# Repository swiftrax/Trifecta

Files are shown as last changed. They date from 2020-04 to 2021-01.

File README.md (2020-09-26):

# Trifecta

A 65% Alice with per key RGB, RGB backlighting and 3 rotary encoders. Designed by 2Moons-JP and swiftrax

# Render

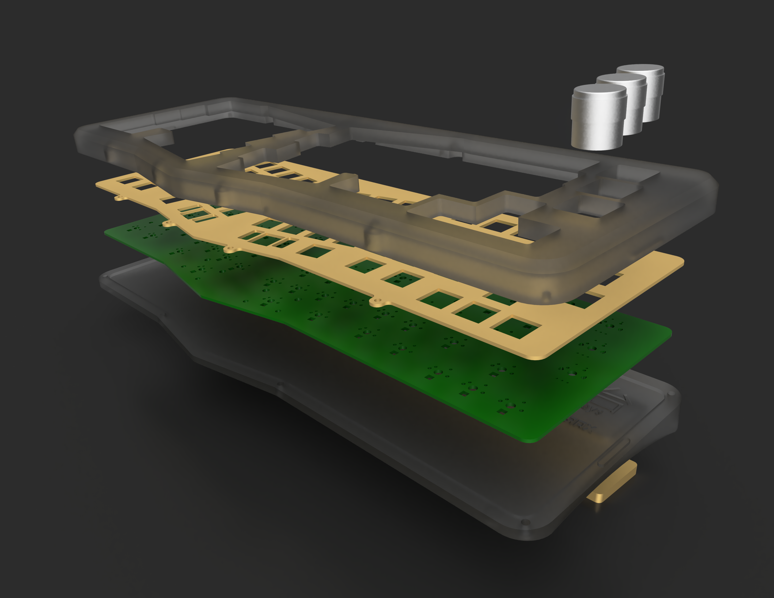
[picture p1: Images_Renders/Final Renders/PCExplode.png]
Renders


# Proto Image

Smoky PC

## License

This repository is under the [GNU GPL V2 license](https://github.com/swiftrax/Trifecta/blob/master/LICENSE). If you plan to sell these pcbs, make sure to read it.

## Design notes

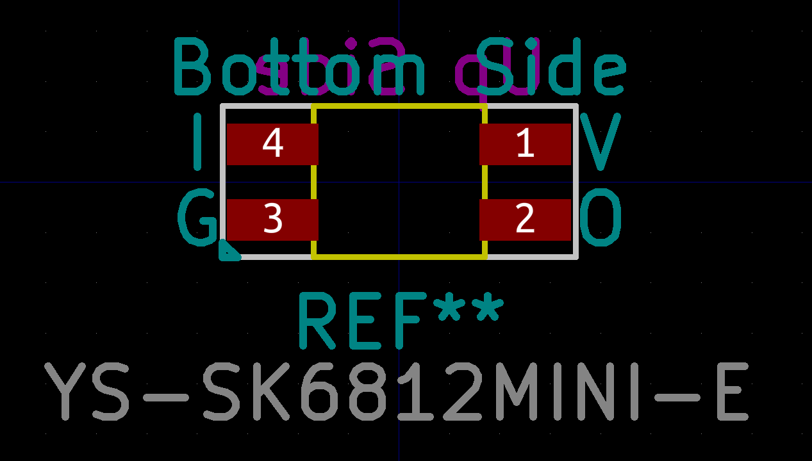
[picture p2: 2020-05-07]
Hardware/Rev06rgbstm32 12Deg/LED_kicad_footprints-master/YS-SK6812MINI-E.png

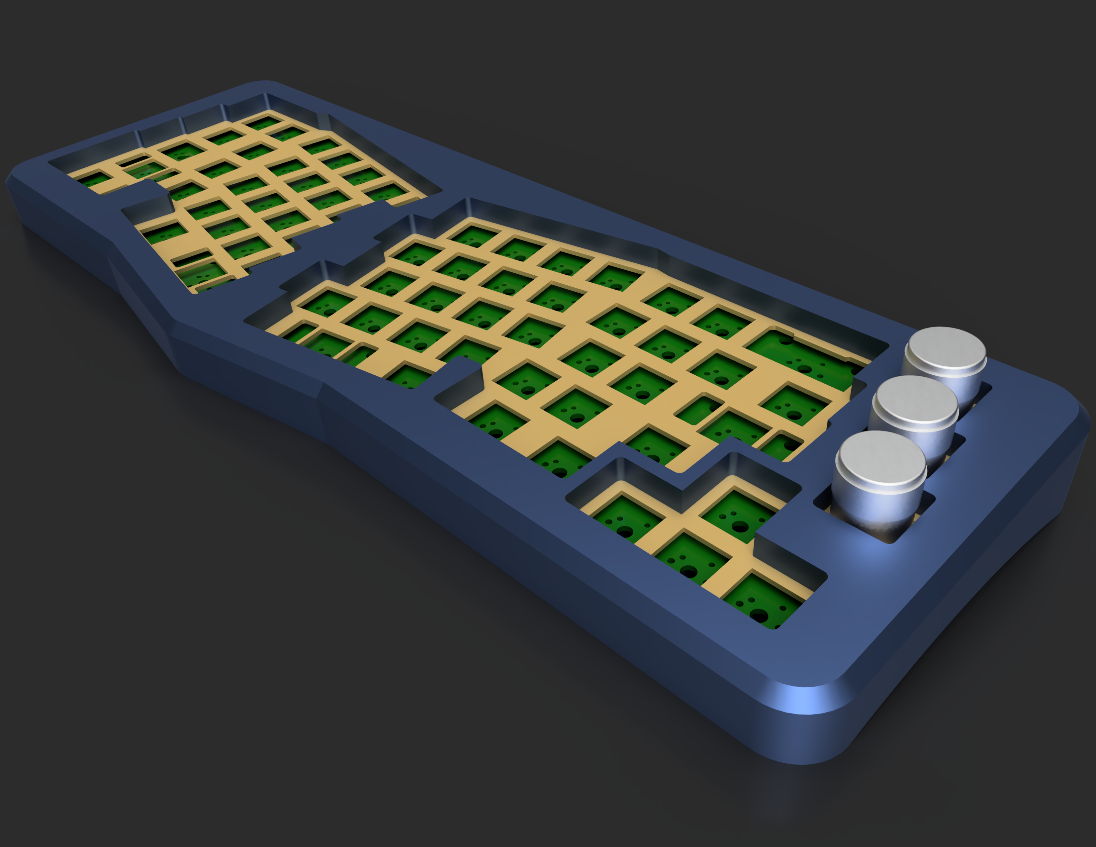
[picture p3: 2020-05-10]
Images_Renders/Final Renders/BlueISO.png

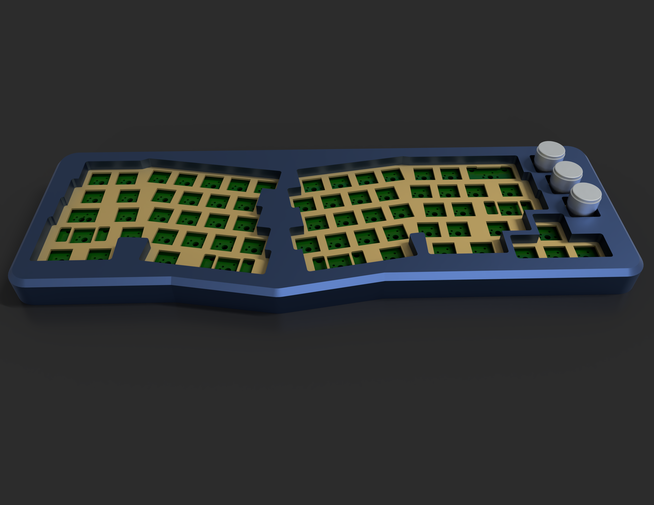
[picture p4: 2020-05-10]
Images_Renders/Final Renders/TypingAngle.png

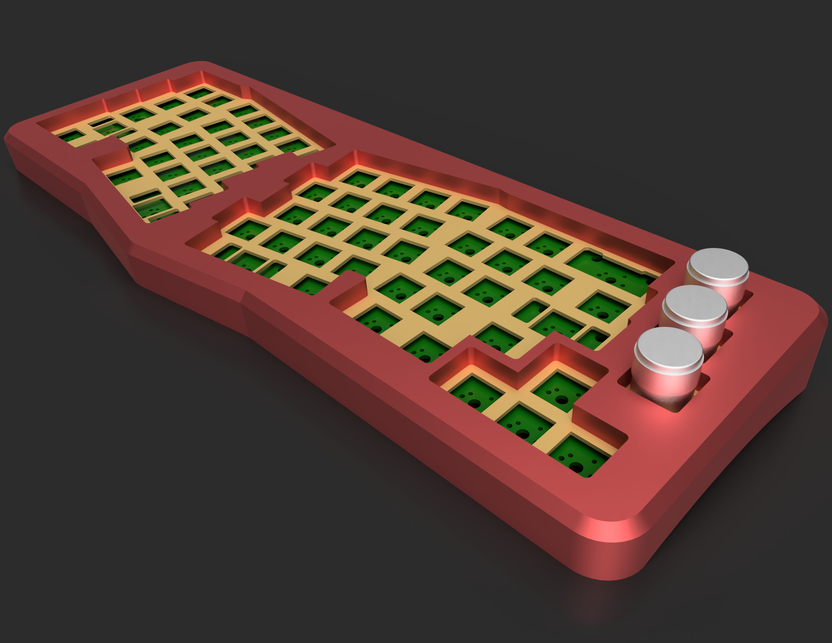
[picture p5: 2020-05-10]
Images_Renders/Final Renders/RedISO.png

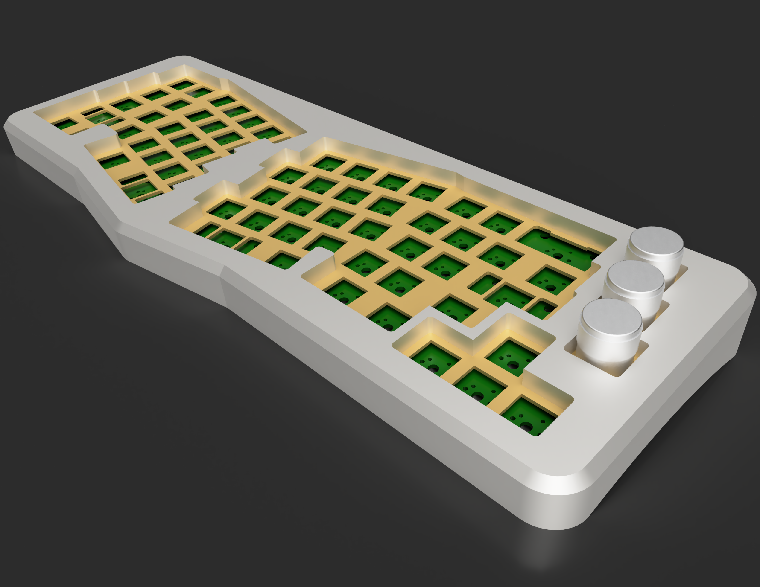
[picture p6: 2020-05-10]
Images_Renders/Final Renders/EWhiteISO.png

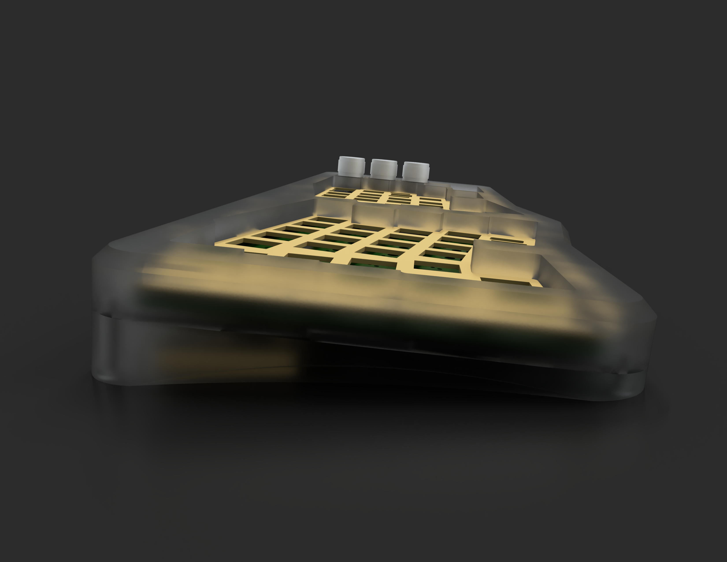
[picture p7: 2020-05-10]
Images_Renders/Final Renders/PCSide.png

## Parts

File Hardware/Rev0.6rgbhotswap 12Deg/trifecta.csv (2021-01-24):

Comment | Designator | Footprint | LCSC | LCSC Part# | Mrf | Part# | Mfr
1uF | C1 | Capacitor_SMD:C_0805_2012Metric |  | C28323 |  | CL21B105KBFNNNE | Samsung Electro-Mechanics
10uF | C16 | Capacitor_SMD:C_0805_2012Metric |  | C15850 |  | CL21A106KAYNNNE | Samsung Electro-Mechanics
0.1uF | C9,C11,C13,C2,C18,C34,C48,C63,C4,C20,C36,C50,C6,C22,C38,C52,C8,C24,C40,C54,C66,C10,C26,C42,C56,C67,C12,C28,C44,C58,C69,C15,C30,C45,C60,C71,C72,C73,C74,C75,C76,C77,C78,C79 | Capacitor_SMD:C_0805_2012Metric |  | C49678 | YAGEO | CC0805KRX7R9BB104
D | D_1,D_17,D_33,D_47,D_62,D_2,D_18,D_34,D_48,D_63,D_3,D_19,D_35,D_49,D_64,D_4,D_20,D_36,D_50,D_5,D_21,D_37,D_51,D_65,D_6,D_22,D_38,D_52,D_7,D_23,D_39,D_53,D_8,D_24,D_40,D_54,D_66,D_9,D_25,D_41,D_55,D_10,D_26,D_42,D_56,D_67,D_11,D_27,D_43,D_57,D_68,D_12,D_28,D_44,D_58,D_69,D_29,D_59,D_70,D_15,D_30,D_45,D_60,D_71,D_16,D_31,D_46,D_61,D_72,D_13 | kbd:D3_SMD_v2 |  | C81598 | Semtech | 1N4148W
500mA | F1 | Fuse:Fuse_1206_3216Metric |  | C70068 |  | nSMD025 | TECHFUSE
USB2_C_Receptacle | J1 | usb-type-c:Mid_Mount-USB_C_HandSoldering
ISP Header | J2 | Connector_PinHeader_2.54mm:PinHeader_2x03_P2.54mm_Vertical
KEYSW | K_1,K_2,K_18,K_34,K_48,K_3,K_19,K_35,K_49,K_4,K_20,K_36,K_50,K_5,K_21,K_37,K_51,K_6,K_22,K_38,K_52,K_7,K_23,K_39,K_53,K_8,K_24,K_40,K_54,K_9,K_25,K_41,K_55,K_10,K_26,K_42,K_56,K_11,K_27,K_43,K_57,K_12,K_28,K_44,K_58,K_13,K_29,K_70,K_14,K_30,K_60,K_71,K_16,K_31,K_46,K_61,K_72 | MX_Only:MXOnly-1U-NoLED
KEYSW | K_15 | MX_Only:MXOnly-2U-ReversedStabilizers-NoLED
KEYSW | K_17 | MX_Only:MXOnly-1.5U-NoLED
KEYSW | K_32,K_33,K_59 | MX_Only:MXOnly-1.75U-NoLED
KEYSW | K_47,K_66,K_45 | MX_Only:MXOnly-2.25U-ReversedStabilizers-NoLED
KEYSW | K_62,K_63,K_64,K_67,K_68,K_69 | MX_Only:MXOnly-1.25U-NoLED
KEYSW | K_65 | MX_Only:MXOnly-2.75U-ReversedStabilizers-NoLED
YS-SK6812MINI-E | LED1,LED17,LED33,LED47,LED62,LED2,LED18,LED34,LED48,LED63,LED3,LED19,LED35,LED49,LED64,LED4,LED20,LED36,LED50,LED5,LED21,LED37,LED51,LED65,LED6,LED22,LED38,LED52,LED7,LED23,LED39,LED53,LED8,LED24,LED40,LED54,LED66,LED9,LED25,LED41,LED55,LED10,LED26,LED42,LED56,LED67,LED11,LED27,LED43,LED57,LED68,LED12,LED28,LED44,LED58,LED69,LED13,LED29,LED59,LED70,LED30,LED45,LED60,LED71,LED72,LED15 | LED_kicad_footprints-master:YS-SK6812MINI-E
10kΩ | R1,R6 | Resistor_SMD:R_0805_2012Metric |  | C17414 | Uniroyal Elec | 0805W8F1002T5E
5.1kΩ | R2,R3 | Resistor_SMD:R_0805_2012Metric |  | C27834 |  | 0805W8F5101T5E | Uniroyal Elec
22Ω | R5,R4 | Resistor_SMD:R_0805_2012Metric |  | C17561 | Uniroyal Elec | 0805W8F220JT5E
510Ω | R7 | Resistor_SMD:R_0805_2012Metric |  | C17734 | Uniroyal Elec | 0805W8F5100T5E
RESET | SW1 | random-keyboard-parts:SKQG-1155865
Rotary_Encoder_Switch | SW3,SW4,SW2 | Keebio-Parts:RotaryEncoder_EC11
ATmega32U4-AU | U1 | Keebio-Parts:ATMEGA32U4-AU |  | C44854 |  | ATMEGA32U4-AU | Microchip Tech
SRV05-4 | U2 | Package_TO_SOT_SMD:SOT-23-6 |  | C127538 |  | SRV05-4 | Yenji Elec
YS-SK6812MINI-E | ULED13,ULED12,ULED11,ULED10,ULED1,ULED2,ULED3,ULED4,ULED5,ULED9,ULED8,ULED6,ULED7,ULED14 | LED_SMD:LED_SK6812MINI_PLCC4_3.5x3.5mm_P1.75mm
16MHz | Y1 | proj_local:Resonator_SMD_muRata_CSTxExxV-3Pin_3.0x1.1mm_HandSoldering_Compact

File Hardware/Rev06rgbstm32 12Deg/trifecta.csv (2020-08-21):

Comment | Designator | Footprint | LCSC
1uF | C1 | Capacitor_SMD:C_0805_2012Metric
10uF | C16 | Capacitor_SMD:C_0805_2012Metric
0.1uF | C2,C4,C6,C8,C9,C10,C11,C12,C13,C15,C18,C20,C22,C24,C26,C28,C30,C34,C36,C38,C40,C42,C44,C45,C48,C50,C52,C54,C56,C58,C60,C63,C66,C67,C69,C71,C72,C73,C74,C75,C76,C77,C78,C79 | Capacitor_SMD:C_0805_2012Metric
D | D_1,D_2,D_3,D_4,D_5,D_6,D_7,D_8,D_9,D_10,D_11,D_12,D_13,D_15,D_16,D_17,D_18,D_19,D_20,D_21,D_22,D_23,D_24,D_25,D_26,D_27,D_28,D_29,D_30,D_31,D_33,D_34,D_35,D_36,D_37,D_38,D_39,D_40,D_41,D_42,D_43,D_44,D_45,D_46,D_47,D_48,D_49,D_50,D_51,D_52,D_53,D_54,D_55,D_56,D_57,D_58,D_59,D_60,D_61,D_62,D_63,D_64,D_65,D_66,D_67,D_68,D_69,D_70,D_71,D_72 | kbd:D3_SMD_v2
500mA | F1 | Fuse:Fuse_1206_3216Metric
USB2_C_Receptacle | J1 | usb-type-c:Mid_Mount-USB_C_HandSoldering
ISP Header | J2 | Connector_PinHeader_2.54mm:PinHeader_2x03_P2.54mm_Vertical
KEYSW | K_1,K_2,K_3,K_4,K_5,K_6,K_7,K_8,K_9,K_10,K_11,K_12,K_13,K_14,K_16,K_18,K_19,K_20,K_21,K_22,K_23,K_24,K_25,K_26,K_27,K_28,K_29,K_30,K_31,K_34,K_35,K_36,K_37,K_38,K_39,K_40,K_41,K_42,K_43,K_44,K_46,K_48,K_49,K_50,K_51,K_52,K_53,K_54,K_55,K_56,K_57,K_58,K_60,K_61,K_70,K_71,K_72 | MX_Only:MXOnly-1U-NoLED
KEYSW | K_15 | MX_Only:MXOnly-2U-ReversedStabilizers-NoLED
KEYSW | K_17 | MX_Only:MXOnly-1.5U-NoLED
KEYSW | K_32,K_33,K_59 | MX_Only:MXOnly-1.75U-NoLED
KEYSW | K_45,K_47,K_66 | MX_Only:MXOnly-2.25U-ReversedStabilizers-NoLED
KEYSW | K_62,K_63,K_64,K_67,K_68,K_69 | MX_Only:MXOnly-1.25U-NoLED
KEYSW | K_65 | MX_Only:MXOnly-2.75U-ReversedStabilizers-NoLED
YS-SK6812MINI-E | LED1,LED2,LED3,LED4,LED5,LED6,LED7,LED8,LED9,LED10,LED11,LED12,LED13,LED15,LED17,LED18,LED19,LED20,LED21,LED22,LED23,LED24,LED25,LED26,LED27,LED28,LED29,LED30,LED33,LED34,LED35,LED36,LED37,LED38,LED39,LED40,LED41,LED42,LED43,LED44,LED45,LED47,LED48,LED49,LED50,LED51,LED52,LED53,LED54,LED55,LED56,LED57,LED58,LED59,LED60,LED62,LED63,LED64,LED65,LED66,LED67,LED68,LED69,LED70,LED71,LED72 | LED_kicad_footprints-master:YS-SK6812MINI-E
10kΩ | R1,R6 | Resistor_SMD:R_0805_2012Metric
5.1kΩ | R2,R3 | Resistor_SMD:R_0805_2012Metric
22Ω | R4,R5 | Resistor_SMD:R_0805_2012Metric
510Ω | R7 | Resistor_SMD:R_0805_2012Metric
RESET | SW1 | random-keyboard-parts:SKQG-1155865
Rotary_Encoder_Switch | SW2,SW3,SW4 | Keebio-Parts:RotaryEncoder_EC11
ATmega32U4-AU | U1 | Keebio-Parts:ATMEGA32U4-AU
SRV05-4 | U2 | Package_TO_SOT_SMD:SOT-23-6
YS-SK6812MINI-E | ULED1,ULED2,ULED3,ULED4,ULED5,ULED6,ULED7,ULED8,ULED9,ULED10,ULED11,ULED12,ULED13,ULED14 | LED_kicad_footprints-master:Underglow YS-SK6812MINI-E
16MHz | Y1 | proj_local:Resonator_SMD_muRata_CSTxExxV-3Pin_3.0x1.1mm_HandSoldering_Compact

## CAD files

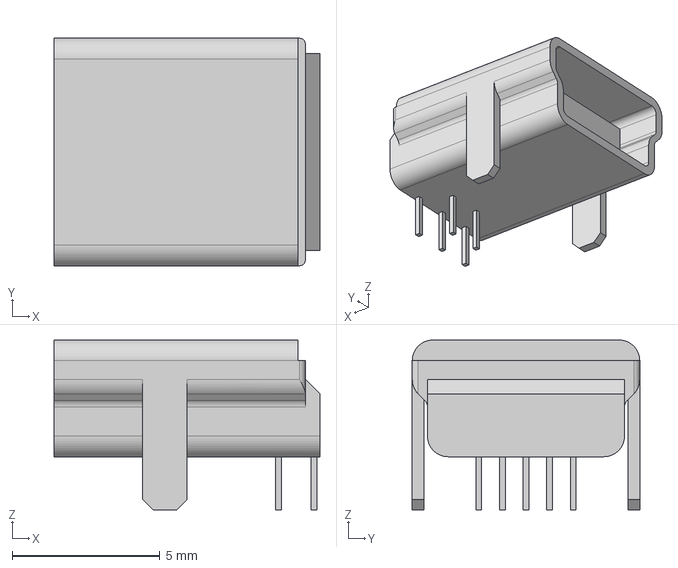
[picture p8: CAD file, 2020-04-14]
Hardware/Rev06rgbstm32 12Deg/random-keyboard-parts.pretty-40eb3bec68eab147745606d36de2775955975cf1/Molex-0548190519.step
9.00 x 7.70 x 5.75 mm

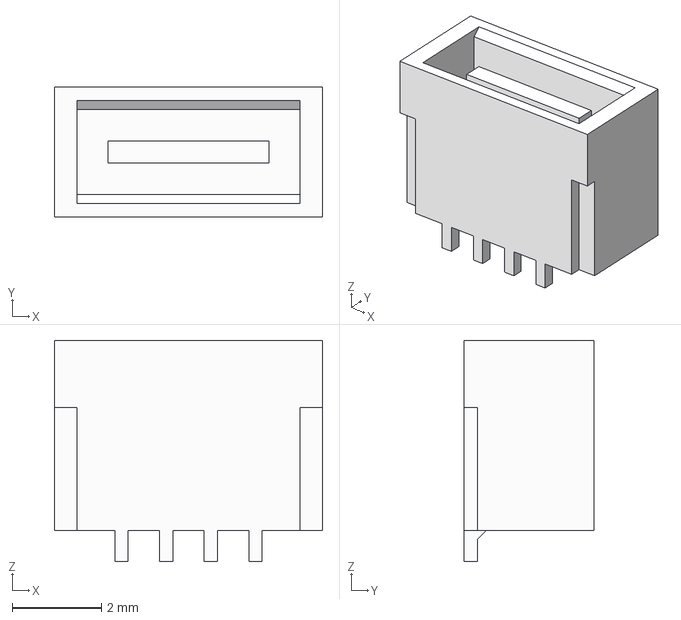
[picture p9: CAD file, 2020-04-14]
Hardware/Rev06rgbstm32 12Deg/random-keyboard-parts.pretty-40eb3bec68eab147745606d36de2775955975cf1/JST-SR-4.step
6.00 x 2.90 x 4.95 mm

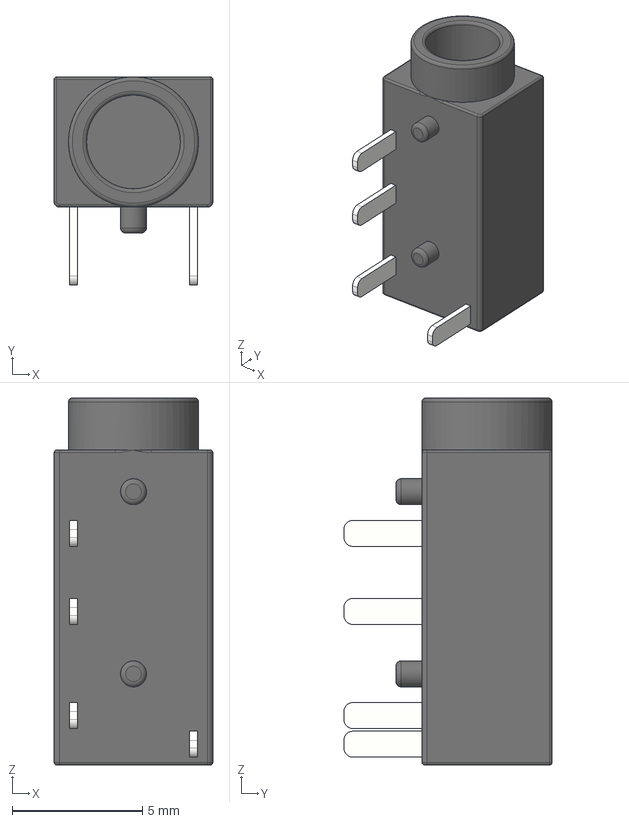
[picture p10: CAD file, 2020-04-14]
Hardware/Rev06rgbstm32 12Deg/random-keyboard-parts.pretty-40eb3bec68eab147745606d36de2775955975cf1/PJ-3200B.step
6.10 x 8.00 x 14.1 mm

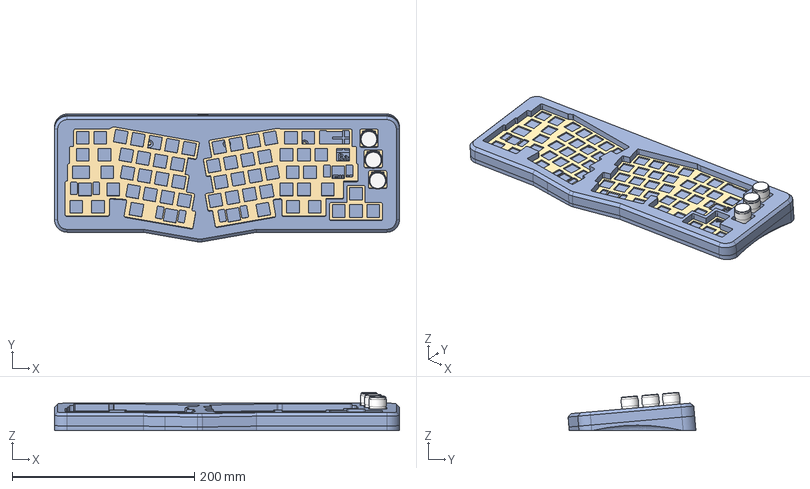
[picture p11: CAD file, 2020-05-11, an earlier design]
Case/Case_Archived/Trifecta Case rev0.3/Trifecta Assembled.step
379.0 x 140.6 x 42.2 mm
plate
top
bottom
weight

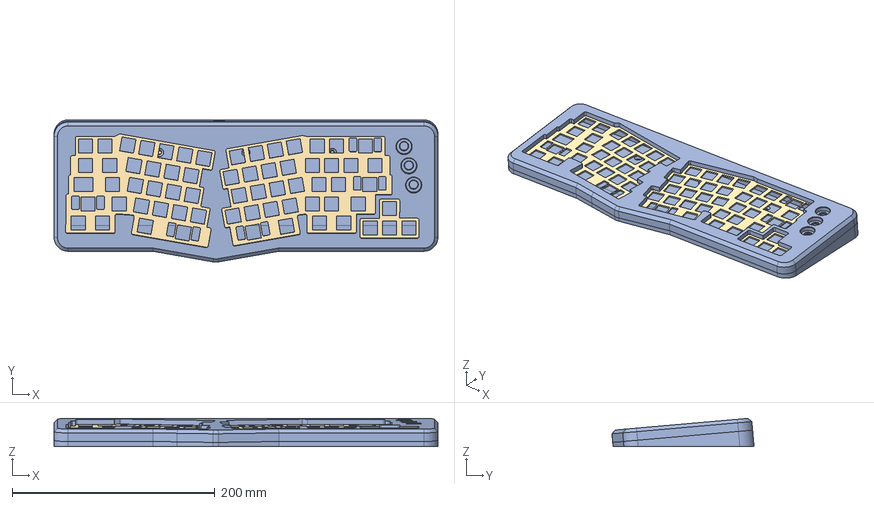
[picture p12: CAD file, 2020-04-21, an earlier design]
Case/Case_Archived/Laser Files/Rev 0.0/DXF/TrifectaCase.step
379.0 x 140.4 x 27.9 mm
plate
top
bottom
weight

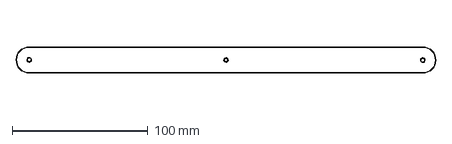
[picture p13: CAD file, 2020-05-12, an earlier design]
Case/Case_Archived/Laser Files/Rev 0.1/DXF/Foot2.dxf
309.0 x 19.2 mm

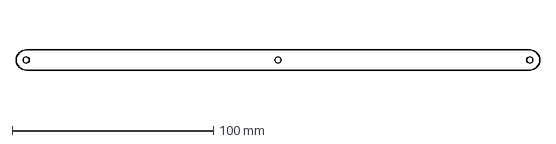
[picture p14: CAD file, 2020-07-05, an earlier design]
Case/Case_Archived/Laser Files/Rev 2.0/DXF/LittleFoot.dxf
260.0 x 10.0 mm

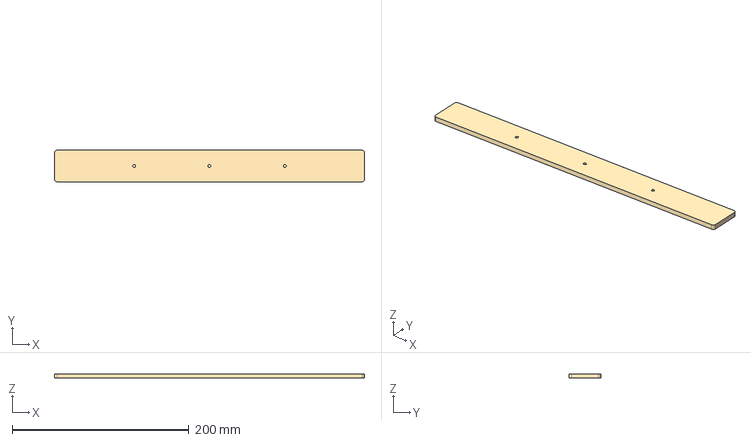
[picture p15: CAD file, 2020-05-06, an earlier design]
Case/Case_Archived/Trifecta Case rev0.1/Weight.step
350.5 x 35.8 x 5.00 mm

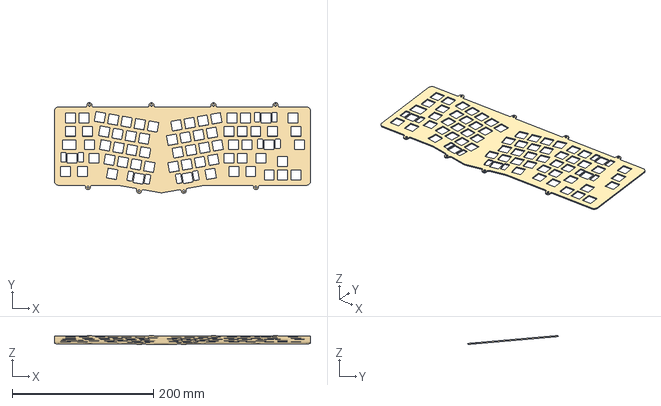
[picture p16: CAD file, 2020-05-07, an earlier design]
Case/Case_Archived/Trifecta Case rev0.2/plate.step
362.0 x 128.1 x 12.8 mm

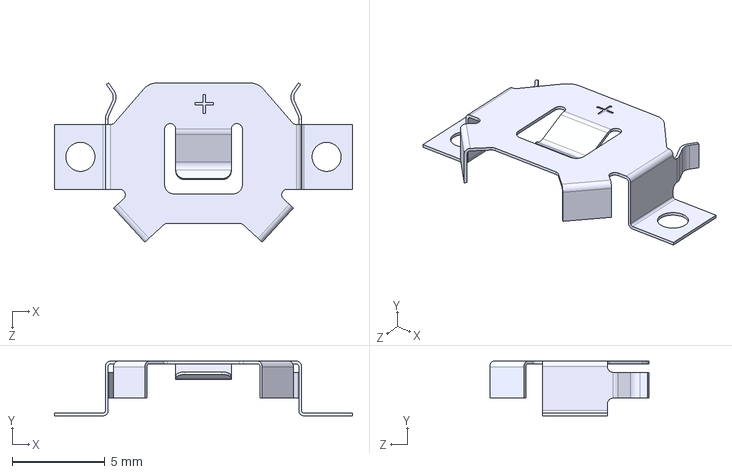
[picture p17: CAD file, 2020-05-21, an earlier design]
Hardware/PCB_Archived/Rev 0.3 RGB Hotswap/AcheronLibrary/3d_models/keystone-PN3030TR.STEP
16.1 x 2.95 x 8.61 mm

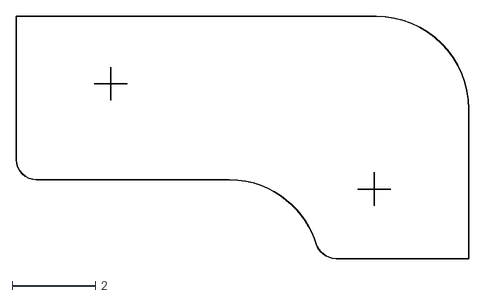
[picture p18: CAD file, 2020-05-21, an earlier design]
Hardware/PCB_Archived/Rev 0.3 RGB Hotswap/AcheronLibrary/graphics/kailhMxSocketOutline.dxf
10.8 x 5.81

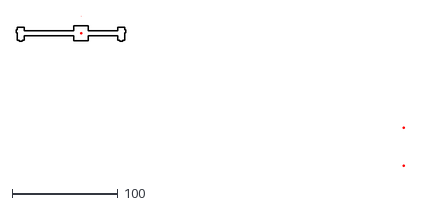
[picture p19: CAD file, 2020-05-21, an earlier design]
Hardware/PCB_Archived/Rev 0.3 RGB Hotswap/AcheronLibrary/graphics/plate_cutouts/6U.dxf
367.0 x 141.8

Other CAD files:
Case/Case_Archived/Laser Files/Rev 0.0/DXF/Bottom.dxf
Case/Case_Archived/Laser Files/Rev 0.0/DXF/BottomElevate.dxf
Case/Case_Archived/Laser Files/Rev 0.0/DXF/MidLayer.dxf
Case/Case_Archived/Laser Files/Rev 0.0/DXF/MiddleElevate.dxf
Case/Case_Archived/Laser Files/Rev 0.0/DXF/SwitchPlate.dxf
Case/Case_Archived/Laser Files/Rev 0.0/DXF/Top.dxf
Case/Case_Archived/Laser Files/Rev 0.0/DXF/TopElevate.dxf
Case/Case_Archived/Laser Files/Rev 0.0/DXF/TopEncoders.dxf
Case/Case_Archived/Laser Files/Rev 0.1/DXF/Bottom.dxf
Case/Case_Archived/Laser Files/Rev 0.1/DXF/Foot1.dxf
Case/Case_Archived/Laser Files/Rev 0.1/DXF/Midlayer.dxf
Case/Case_Archived/Laser Files/Rev 0.1/DXF/Plate.dxf
Case/Case_Archived/Laser Files/Rev 0.1/DXF/Top.dxf
Case/Case_Archived/Laser Files/Rev 2.0/DXF/BackPlate.dxf
Case/Case_Archived/Laser Files/Rev 2.0/DXF/BigFoot.dxf
Case/Case_Archived/Laser Files/Rev 2.0/DXF/HiPro.dxf
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

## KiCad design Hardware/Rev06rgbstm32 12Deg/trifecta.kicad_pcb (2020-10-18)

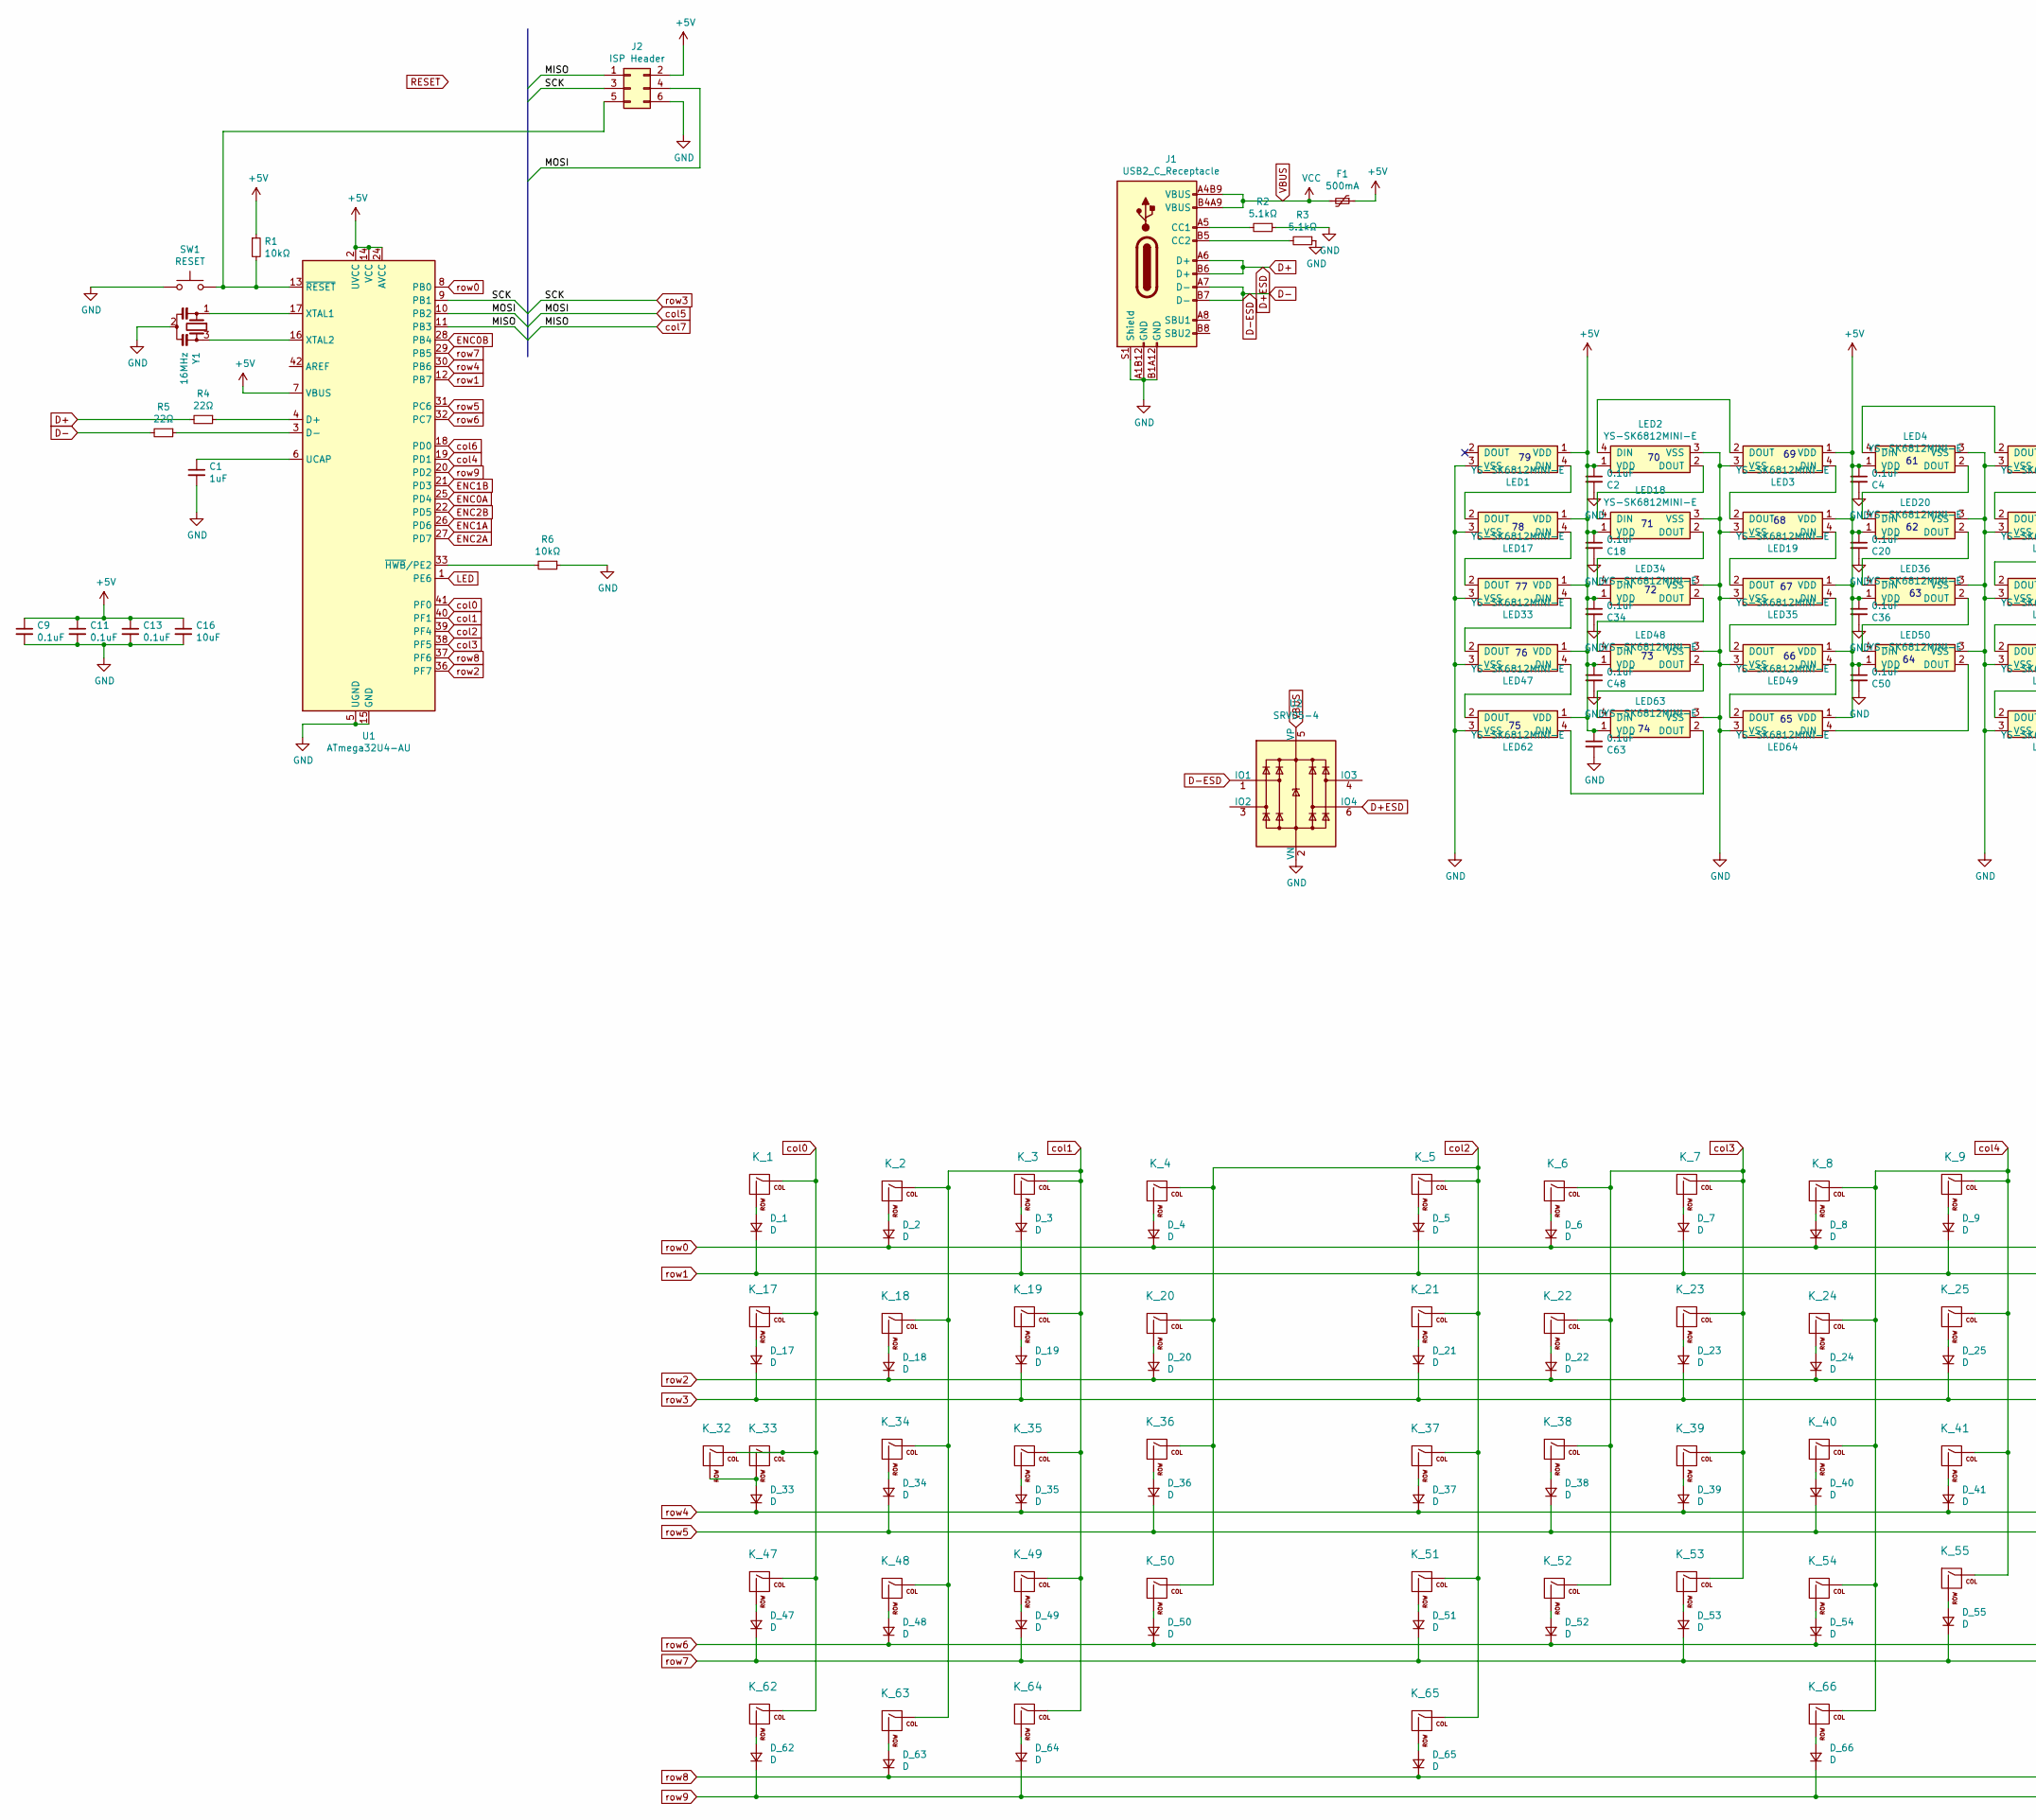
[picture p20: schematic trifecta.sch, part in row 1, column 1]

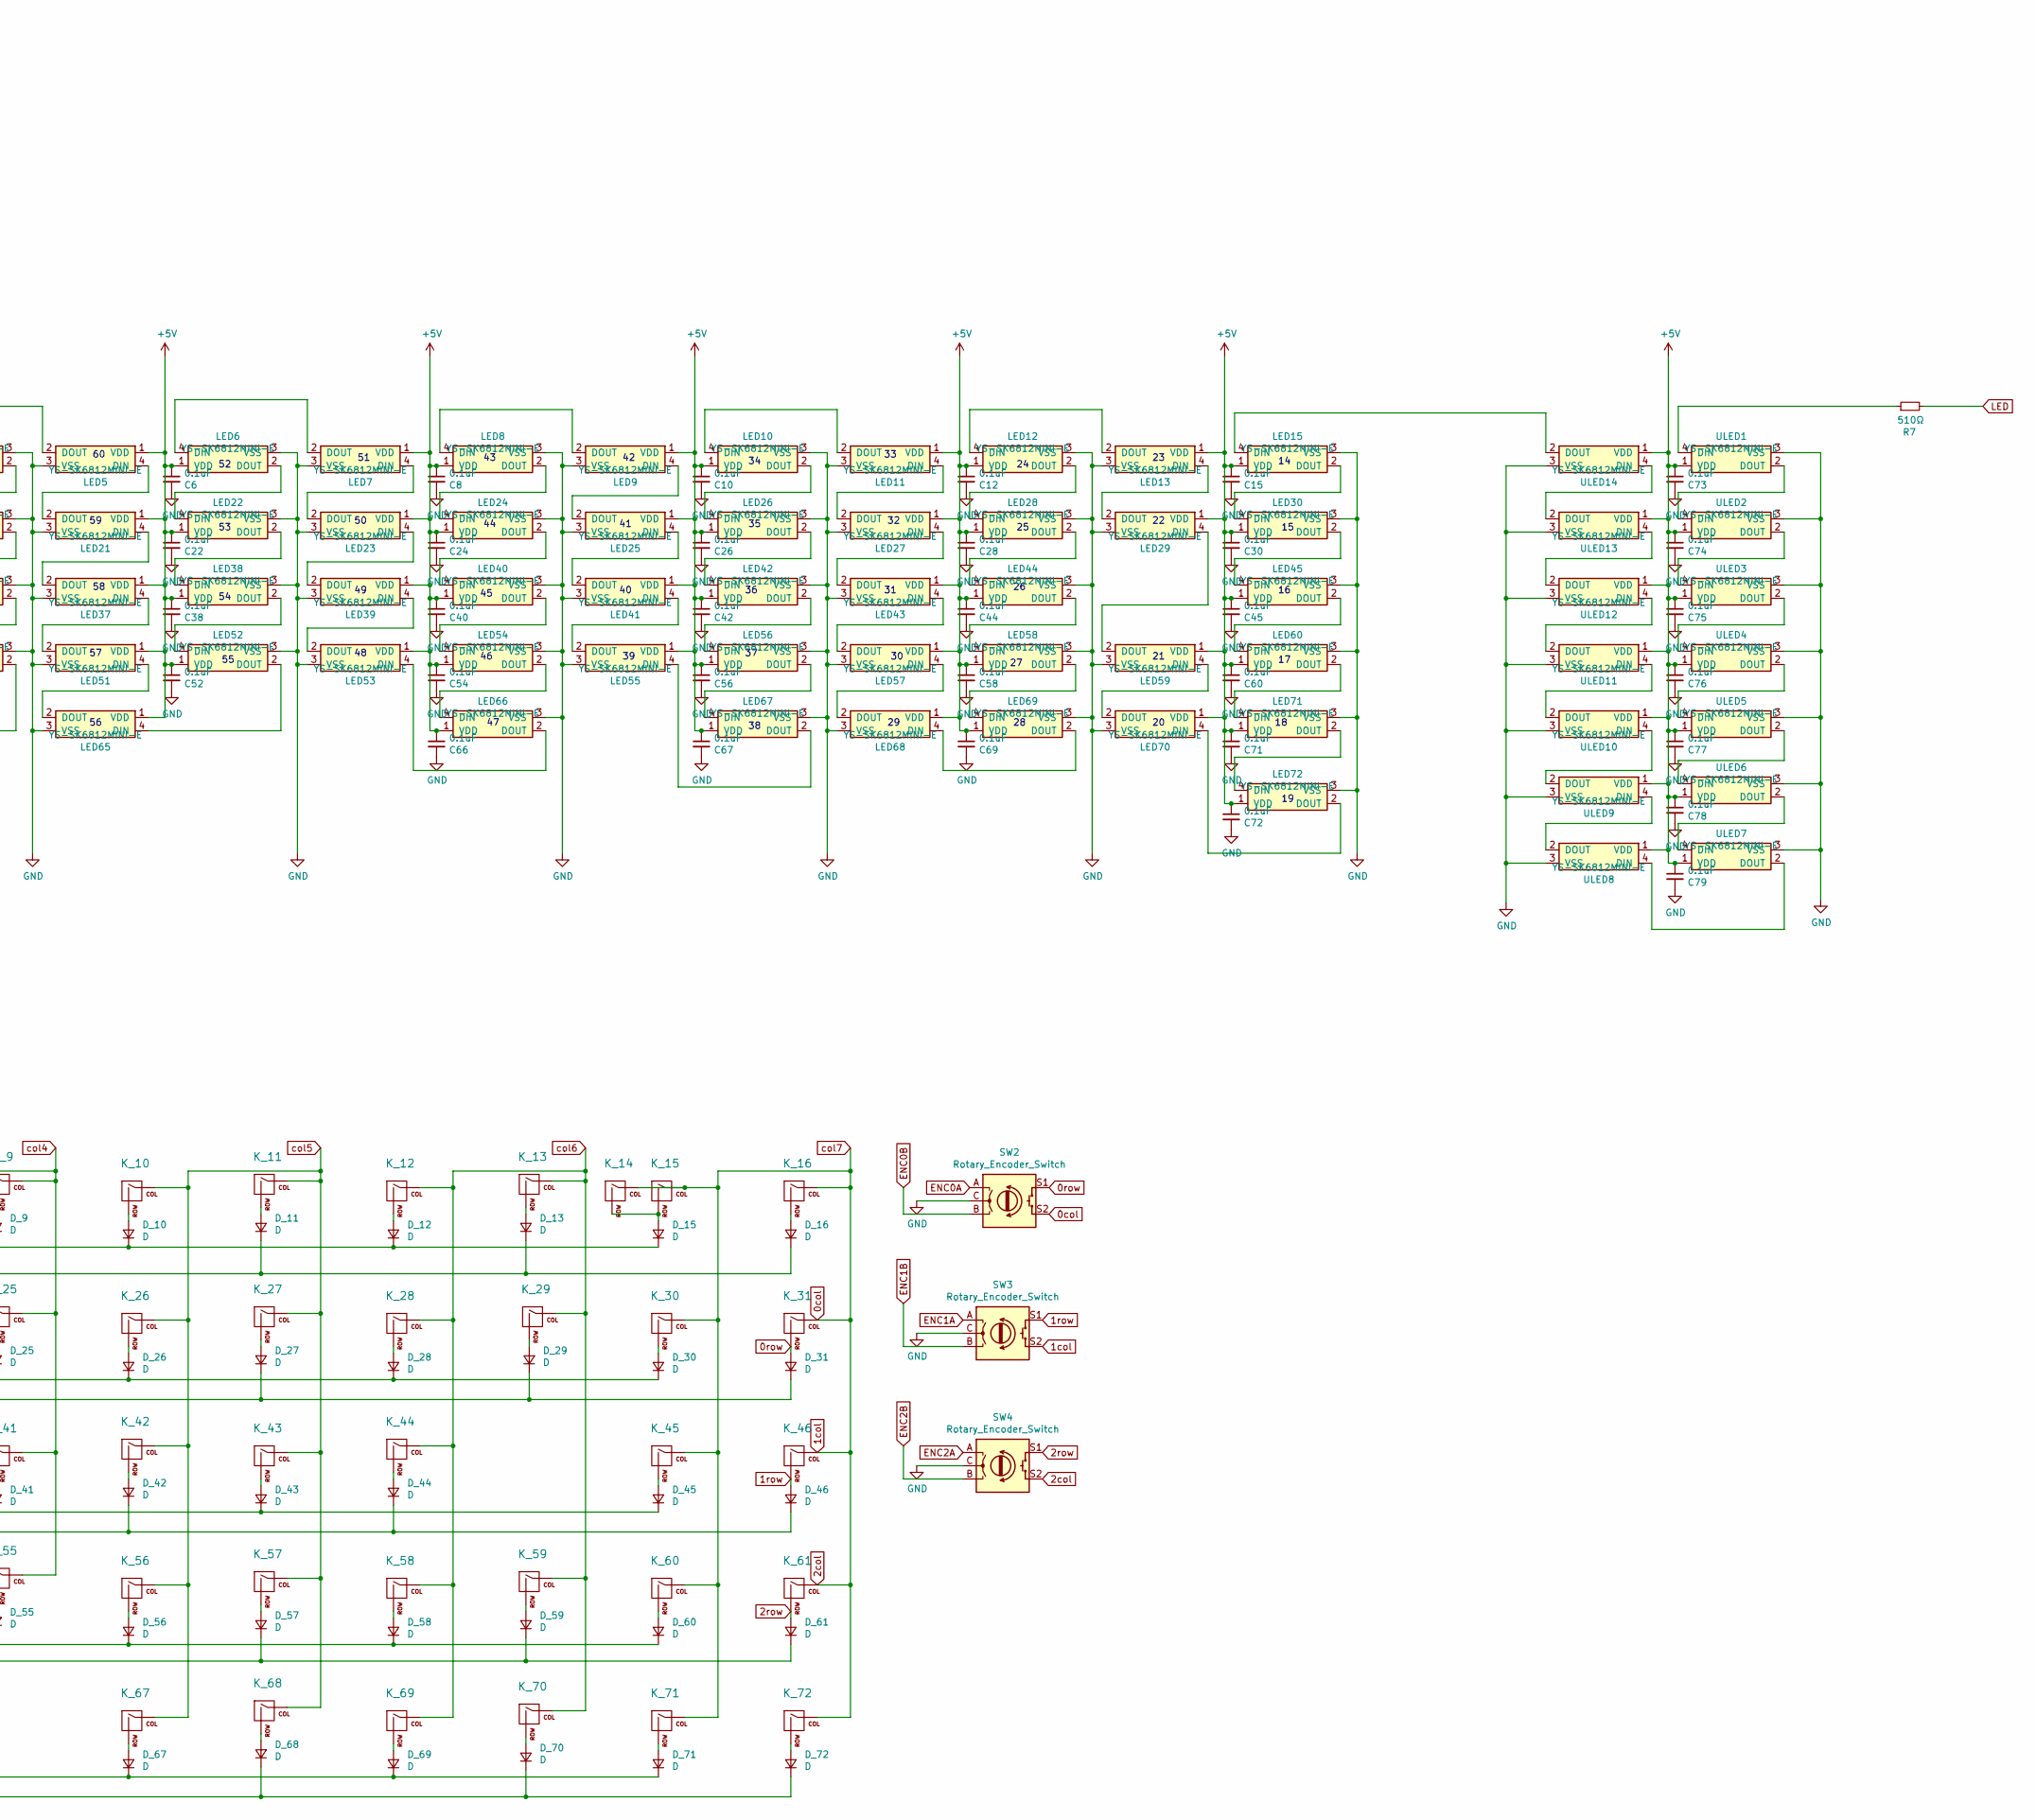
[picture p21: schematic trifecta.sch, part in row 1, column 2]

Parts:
C1: 1uF; C_0805_2012Metric; Part# CL21B105KBFNNNE; LCSC Part# C28323
C2, C4, C6, C8, C9, C10, C11, C12, C13, C15, C18, C20, C22, C24, C26, C28, C30, C34, C36, C38, C40, C42, C44, C45, C48, C50, C52, C54, C56, C58, C60, C63, C66, C67, C69, C71, C72, C73, C74, C75, C76, C77, C78, C79: 0.1uF; C_0805_2012Metric; Part# CC0805KRX7R9BB104; LCSC Part# C49678
C16: 10uF; C_0805_2012Metric; Part# CL21A106KAYNNNE; LCSC Part# C15850
D_1, D_2, D_3, D_4, D_5, D_6, D_7, D_8, D_9, D_10, D_11, D_12, D_13, D_15, D_16, D_17, D_18, D_19, D_20, D_21, D_22, D_23, D_24, D_25, D_26, D_27, D_28, D_29, D_30, D_31, D_33, D_34, D_35, D_36, D_37, D_38, D_39, D_40, D_41, D_42, D_43, D_44, D_45, D_46, D_47, D_48, D_49, D_50, D_51, D_52, D_53, D_54, D_55, D_56, D_57, D_58, D_59, D_60, D_61, D_62, D_63, D_64, D_65, D_66, D_67, D_68, D_69, D_70, D_71, D_72: D; D3_SMD_v2; Part# 1N4148W; LCSC Part# C81598
F1: 500mA; Fuse_1206_3216Metric; Part# nSMD025; LCSC Part# C70068
J1: USB2_C_Receptacle; Mid_Mount-USB_C_HandSoldering
J2: ISP Header; PinHeader_2x03_P2.54mm_Vertical
K_1, K_2, K_3, K_4, K_5, K_6, K_7, K_8, K_9, K_10, K_11, K_12, K_13, K_14, K_16, K_18, K_19, K_20, K_21, K_22, K_23, K_24, K_25, K_26, K_27, K_28, K_29, K_30, K_31, K_34, K_35, K_36, K_37, K_38, K_39, K_40, K_41, K_42, K_43, K_44, K_46, K_48, K_49, K_50, K_51, K_52, K_53, K_54, K_55, K_56, K_57, K_58, K_60, K_61, K_70, K_71, K_72: KEYSW; MXOnly-1U-NoLED
K_15: KEYSW; MXOnly-2U-ReversedStabilizers-NoLED
K_17: KEYSW; MXOnly-1.5U-NoLED
K_32, K_33, K_59: KEYSW; MXOnly-1.75U-NoLED
K_45, K_47, K_66: KEYSW; MXOnly-2.25U-ReversedStabilizers-NoLED
K_62, K_63, K_64, K_67, K_68, K_69: KEYSW; MXOnly-1.25U-NoLED
K_65: KEYSW; MXOnly-2.75U-ReversedStabilizers-NoLED
LED1, LED2, LED3, LED4, LED5, LED6, LED7, LED8, LED9, LED10, LED11, LED12, LED13, LED15, LED17, LED18, LED19, LED20, LED21, LED22, LED23, LED24, LED25, LED26, LED27, LED28, LED29, LED30, LED33, LED34, LED35, LED36, LED37, LED38, LED39, LED40, LED41, LED42, LED43, LED44, LED45, LED47, LED48, LED49, LED50, LED51, LED52, LED53, LED54, LED55, LED56, LED57, LED58, LED59, LED60, LED62, LED63, LED64, LED65, LED66, LED67, LED68, LED69, LED70, LED71, LED72: YS-SK6812MINI-E
R1, R6: 10kΩ; R_0805_2012Metric; Part# 0805W8F1002T5E; LCSC Part# C17414
R2, R3: 5.1kΩ; R_0805_2012Metric; Part# 0805W8F5101T5E; LCSC Part# C27834
R4, R5: 22Ω; R_0805_2012Metric; Part# 0805W8F220JT5E; LCSC Part# C17561
R7: 510Ω; R_0805_2012Metric; Part# 0805W8F5100T5E; LCSC Part# C17734
SW1: RESET; SKQG-1155865
SW2, SW3, SW4: Rotary_Encoder_Switch; RotaryEncoder_EC11
U1: ATmega32U4-AU; ATMEGA32U4-AU; Part# ATMEGA32U4-AU; LCSC Part# C44854
U2: SRV05-4; SOT-23-6; Part# SRV05-4; LCSC Part# C127538
ULED1, ULED2, ULED3, ULED4, ULED5, ULED6, ULED7, ULED8, ULED9, ULED10, ULED11, ULED12, ULED13, ULED14: YS-SK6812MINI-E; LED_SK6812MINI_PLCC4_3.5x3.5mm_P1.75mm
Y1: 16MHz; Resonator_SMD_muRata_CSTxExxV-3Pin_3.0x1.1mm_HandSoldering_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

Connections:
0col: J2.1, K_14.1 (COL), K_15.1 (COL), K_16.1 (COL), K_30.1 (COL), K_31.1 (COL), K_45.1 (COL), K_46.1 (COL), K_60.1 (COL), K_61.1 (COL), K_71.1 (COL), K_72.1 (COL), SW2.S2, SW3.S2, SW4.S2, U1.11 (PB3)
0row: D_31.2 (A), K_31.2 (ROW), SW2.S1
1row: D_46.2 (A), K_46.2 (ROW), SW3.S1
2row: D_61.2 (A), K_61.2 (ROW), SW4.S1
+5V: C2.1, C4.1, C6.1, C8.1, C9.1, C10.1, C11.1, C12.1, C13.1, C15.1, C16.1, C18.1, C20.1, C22.1, C24.1, C26.1, C28.1, C30.1, C34.1, C36.1, C38.1, C40.1, C42.1, C44.1, C45.1, C48.1, C50.1, C52.1, C54.1, C56.1, C58.1, C60.1, C63.1, C66.1, C67.1, C69.1, C71.1, C72.1, C73.1, C74.1, C75.1, C76.1, C77.1, C78.1, C79.1, F1.1, J2.2, LED1.1 (VDD), LED2.1 (VDD), LED3.1 (VDD), LED4.1 (VDD), LED5.1 (VDD), LED6.1 (VDD), LED7.1 (VDD), LED8.1 (VDD), LED9.1 (VDD), LED10.1 (VDD), LED11.1 (VDD), LED12.1 (VDD), LED13.1 (VDD), LED15.1 (VDD), LED17.1 (VDD), LED18.1 (VDD), LED19.1 (VDD), LED20.1 (VDD), LED21.1 (VDD), LED22.1 (VDD), LED23.1 (VDD), LED24.1 (VDD), LED25.1 (VDD), LED26.1 (VDD), LED27.1 (VDD), LED28.1 (VDD), LED29.1 (VDD), LED30.1 (VDD), LED33.1 (VDD), LED34.1 (VDD), LED35.1 (VDD), LED36.1 (VDD), LED37.1 (VDD), LED38.1 (VDD), LED39.1 (VDD), LED40.1 (VDD), LED41.1 (VDD), LED42.1 (VDD), LED43.1 (VDD), LED44.1 (VDD), LED45.1 (VDD), LED47.1 (VDD), LED48.1 (VDD), LED49.1 (VDD), LED50.1 (VDD), LED51.1 (VDD), LED52.1 (VDD), LED53.1 (VDD), LED54.1 (VDD), LED55.1 (VDD), LED56.1 (VDD), LED57.1 (VDD), LED58.1 (VDD), LED59.1 (VDD), LED60.1 (VDD), LED62.1 (VDD), LED63.1 (VDD), LED64.1 (VDD), LED65.1 (VDD), LED66.1 (VDD), LED67.1 (VDD), LED68.1 (VDD), LED69.1 (VDD), LED70.1 (VDD), LED71.1 (VDD), LED72.1 (VDD), R1.1, U1.2 (UVCC), U1.7 (VBUS), U1.14 (VCC), U1.24 (AVCC), U1.34 (VCC), U1.44 (AVCC), ULED1.1 (VDD), ULED2.1 (VDD), ULED3.1 (VDD), ULED4.1 (VDD), ULED5.1 (VDD), ULED6.1 (VDD), ULED7.1 (VDD), ULED8.1 (VDD), ULED9.1 (VDD), ULED10.1 (VDD), ULED11.1 (VDD), ULED12.1 (VDD), ULED13.1 (VDD), ULED14.1 (VDD)
D+: J1.A6 (D+), J1.B6 (D+), R4.2, U2.6 (IO4)
D-: J1.A7 (D-), J1.B7 (D-), R5.2, U2.1 (IO1)
ENC0A: SW2.A, U1.25 (PD4)
ENC0B: SW2.B, U1.28 (PB4)
ENC1A: SW3.A, U1.26 (PD6)
ENC1B: SW3.B, U1.21 (PD3)
ENC2A: SW4.A, U1.27 (PD7)
ENC2B: SW4.B, U1.22 (PD5)
GND: C1.2, C2.2, C4.2, C6.2, C8.2, C9.2, C10.2, C11.2, C12.2, C13.2, C15.2, C16.2, C18.2, C20.2, C22.2, C24.2, C26.2, C28.2, C30.2, C34.2, C36.2, C38.2, C40.2, C42.2, C44.2, C45.2, C48.2, C50.2, C52.2, C54.2, C56.2, C58.2, C60.2, C63.2, C66.2, C67.2, C69.2, C71.2, C72.2, C73.2, C74.2, C75.2, C76.2, C77.2, C78.2, C79.2, J1.A1B12 (GND), J1.B1A12 (GND), J1.S1 (Shield), J2.6, LED1.3 (VSS), LED2.3 (VSS), LED3.3 (VSS), LED4.3 (VSS), LED5.3 (VSS), LED6.3 (VSS), LED7.3 (VSS), LED8.3 (VSS), LED9.3 (VSS), LED10.3 (VSS), LED11.3 (VSS), LED12.3 (VSS), LED13.3 (VSS), LED15.3 (VSS), LED17.3 (VSS), LED18.3 (VSS), LED19.3 (VSS), LED20.3 (VSS), LED21.3 (VSS), LED22.3 (VSS), LED23.3 (VSS), LED24.3 (VSS), LED25.3 (VSS), LED26.3 (VSS), LED27.3 (VSS), LED28.3 (VSS), LED29.3 (VSS), LED30.3 (VSS), LED33.3 (VSS), LED34.3 (VSS), LED35.3 (VSS), LED36.3 (VSS), LED37.3 (VSS), LED38.3 (VSS), LED39.3 (VSS), LED40.3 (VSS), LED41.3 (VSS), LED42.3 (VSS), LED43.3 (VSS), LED44.3 (VSS), LED45.3 (VSS), LED47.3 (VSS), LED48.3 (VSS), LED49.3 (VSS), LED50.3 (VSS), LED51.3 (VSS), LED52.3 (VSS), LED53.3 (VSS), LED54.3 (VSS), LED55.3 (VSS), LED56.3 (VSS), LED57.3 (VSS), LED58.3 (VSS), LED59.3 (VSS), LED60.3 (VSS), LED62.3 (VSS), LED63.3 (VSS), LED64.3 (VSS), LED65.3 (VSS), LED66.3 (VSS), LED67.3 (VSS), LED68.3 (VSS), LED69.3 (VSS), LED70.3 (VSS), LED71.3 (VSS), LED72.3 (VSS), R2.1, R3.1, R6.1, SW1.1, SW2.C, SW3.C, SW4.C, U1.5 (UGND), U1.15 (GND), U1.23 (GND), U1.35 (GND), U1.43 (GND), U2.2 (VN), ULED1.3 (VSS), ULED2.3 (VSS), ULED3.3 (VSS), ULED4.3 (VSS), ULED5.3 (VSS), ULED6.3 (VSS), ULED7.3 (VSS), ULED8.3 (VSS), ULED9.3 (VSS), ULED10.3 (VSS), ULED11.3 (VSS), ULED12.3 (VSS), ULED13.3 (VSS), ULED14.3 (VSS), Y1.2
LED: R7.2, U1.1 (PE6)
unnamed: C1.1, U1.6 (UCAP)
unnamed: D_1.2 (A), K_1.2 (ROW)
unnamed: D_2.2 (A), K_2.2 (ROW)
unnamed: D_3.2 (A), K_3.2 (ROW)
unnamed: D_4.2 (A), K_4.2 (ROW)
unnamed: D_5.2 (A), K_5.2 (ROW)
unnamed: D_6.2 (A), K_6.2 (ROW)
unnamed: D_7.2 (A), K_7.2 (ROW)
unnamed: D_8.2 (A), K_8.2 (ROW)
unnamed: D_9.2 (A), K_9.2 (ROW)
unnamed: D_10.2 (A), K_10.2 (ROW)
unnamed: D_11.2 (A), K_11.2 (ROW)
unnamed: D_12.2 (A), K_12.2 (ROW)
unnamed: D_13.2 (A), K_13.2 (ROW)
unnamed: D_15.2 (A), K_14.2 (ROW), K_15.2 (ROW)
unnamed: D_16.2 (A), K_16.2 (ROW)
unnamed: D_17.2 (A), K_17.2 (ROW)
unnamed: D_18.2 (A), K_18.2 (ROW)
unnamed: D_19.2 (A), K_19.2 (ROW)
unnamed: D_20.2 (A), K_20.2 (ROW)
unnamed: D_21.2 (A), K_21.2 (ROW)
unnamed: D_22.2 (A), K_22.2 (ROW)
unnamed: D_23.2 (A), K_23.2 (ROW)
unnamed: D_24.2 (A), K_24.2 (ROW)
unnamed: D_25.2 (A), K_25.2 (ROW)
unnamed: D_26.2 (A), K_26.2 (ROW)
unnamed: D_27.2 (A), K_27.2 (ROW)
unnamed: D_28.2 (A), K_28.2 (ROW)
unnamed: D_29.2 (A), K_29.2 (ROW)
unnamed: D_30.2 (A), K_30.2 (ROW)
unnamed: D_33.2 (A), K_32.2 (ROW), K_33.2 (ROW)
unnamed: D_34.2 (A), K_34.2 (ROW)
unnamed: D_35.2 (A), K_35.2 (ROW)
unnamed: D_36.2 (A), K_36.2 (ROW)
unnamed: D_37.2 (A), K_37.2 (ROW)
unnamed: D_38.2 (A), K_38.2 (ROW)
unnamed: D_39.2 (A), K_39.2 (ROW)
unnamed: D_40.2 (A), K_40.2 (ROW)
unnamed: D_41.2 (A), K_41.2 (ROW)
unnamed: D_42.2 (A), K_42.2 (ROW)
unnamed: D_43.2 (A), K_43.2 (ROW)
unnamed: D_44.2 (A), K_44.2 (ROW)
unnamed: D_45.2 (A), K_45.2 (ROW)
unnamed: D_47.2 (A), K_47.2 (ROW)
unnamed: D_48.2 (A), K_48.2 (ROW)
unnamed: D_49.2 (A), K_49.2 (ROW)
unnamed: D_50.2 (A), K_50.2 (ROW)
unnamed: D_51.2 (A), K_51.2 (ROW)
unnamed: D_52.2 (A), K_52.2 (ROW)
unnamed: D_53.2 (A), K_53.2 (ROW)
unnamed: D_54.2 (A), K_54.2 (ROW)
unnamed: D_55.2 (A), K_55.2 (ROW)
unnamed: D_56.2 (A), K_56.2 (ROW)
unnamed: D_57.2 (A), K_57.2 (ROW)
unnamed: D_58.2 (A), K_58.2 (ROW)
unnamed: D_59.2 (A), K_59.2 (ROW)
unnamed: D_60.2 (A), K_60.2 (ROW)
unnamed: D_62.2 (A), K_62.2 (ROW)
unnamed: D_63.2 (A), K_63.2 (ROW)
unnamed: D_64.2 (A), K_64.2 (ROW)
unnamed: D_65.2 (A), K_65.2 (ROW)
unnamed: D_66.2 (A), K_66.2 (ROW)
unnamed: D_67.2 (A), K_67.2 (ROW)
unnamed: D_68.2 (A), K_68.2 (ROW)
unnamed: D_69.2 (A), K_69.2 (ROW)
unnamed: D_70.2 (A), K_70.2 (ROW)
unnamed: D_71.2 (A), K_71.2 (ROW)
unnamed: D_72.2 (A), K_72.2 (ROW)
unnamed: J1.A5 (CC1), R2.2
unnamed: J1.B5 (CC2), R3.2
unnamed: J2.5, R1.2, SW1.2, U1.13 (~RESET)
unnamed: LED1.4 (DIN), LED17.2 (DOUT)
unnamed: LED2.4 (DIN), LED3.2 (DOUT)
unnamed: LED4.4 (DIN), LED5.2 (DOUT)
unnamed: LED6.4 (DIN), LED7.2 (DOUT)
unnamed: LED8.4 (DIN), LED9.2 (DOUT)
unnamed: LED10.2 (DOUT), LED26.4 (DIN)
unnamed: LED10.4 (DIN), LED11.2 (DOUT)
unnamed: LED11.4 (DIN), LED27.2 (DOUT)
unnamed: LED12.2 (DOUT), LED28.4 (DIN)
unnamed: LED12.4 (DIN), LED13.2 (DOUT)
unnamed: LED13.4 (DIN), LED29.2 (DOUT)
unnamed: LED15.2 (DOUT), LED30.4 (DIN)
unnamed: LED15.4 (DIN), ULED14.2 (DOUT)
unnamed: LED17.4 (DIN), LED33.2 (DOUT)
unnamed: LED18.2 (DOUT), LED34.4 (DIN)
unnamed: LED2.2 (DOUT), LED18.4 (DIN)
unnamed: LED3.4 (DIN), LED19.2 (DOUT)
unnamed: LED19.4 (DIN), LED35.2 (DOUT)
unnamed: LED20.2 (DOUT), LED36.4 (DIN)
unnamed: LED4.2 (DOUT), LED20.4 (DIN)
unnamed: LED5.4 (DIN), LED21.2 (DOUT)
unnamed: LED21.4 (DIN), LED37.2 (DOUT)
unnamed: LED22.2 (DOUT), LED38.4 (DIN)
unnamed: LED6.2 (DOUT), LED22.4 (DIN)
unnamed: LED7.4 (DIN), LED23.2 (DOUT)
unnamed: LED23.4 (DIN), LED39.2 (DOUT)
unnamed: LED24.2 (DOUT), LED40.4 (DIN)
unnamed: LED8.2 (DOUT), LED24.4 (DIN)
unnamed: LED9.4 (DIN), LED25.2 (DOUT)
unnamed: LED25.4 (DIN), LED41.2 (DOUT)
unnamed: LED26.2 (DOUT), LED42.4 (DIN)
unnamed: LED27.4 (DIN), LED43.2 (DOUT)
unnamed: LED28.2 (DOUT), LED44.4 (DIN)
unnamed: LED29.4 (DIN), LED59.2 (DOUT)
unnamed: LED30.2 (DOUT), LED45.4 (DIN)
unnamed: LED33.4 (DIN), LED47.2 (DOUT)
unnamed: LED34.2 (DOUT), LED48.4 (DIN)
unnamed: LED35.4 (DIN), LED49.2 (DOUT)
unnamed: LED36.2 (DOUT), LED50.4 (DIN)
unnamed: LED37.4 (DIN), LED51.2 (DOUT)
unnamed: LED38.2 (DOUT), LED52.4 (DIN)
unnamed: LED39.4 (DIN), LED53.2 (DOUT)
unnamed: LED40.2 (DOUT), LED54.4 (DIN)
unnamed: LED41.4 (DIN), LED55.2 (DOUT)
unnamed: LED42.2 (DOUT), LED56.4 (DIN)
unnamed: LED43.4 (DIN), LED57.2 (DOUT)
unnamed: LED44.2 (DOUT), LED58.4 (DIN)
unnamed: LED45.2 (DOUT), LED60.4 (DIN)
unnamed: LED47.4 (DIN), LED62.2 (DOUT)
unnamed: LED48.2 (DOUT), LED63.4 (DIN)
unnamed: LED49.4 (DIN), LED64.2 (DOUT)
unnamed: LED50.2 (DOUT), LED64.4 (DIN)
unnamed: LED51.4 (DIN), LED65.2 (DOUT)
unnamed: LED52.2 (DOUT), LED65.4 (DIN)
unnamed: LED53.4 (DIN), LED66.2 (DOUT)
unnamed: LED54.2 (DOUT), LED66.4 (DIN)
unnamed: LED55.4 (DIN), LED67.2 (DOUT)
unnamed: LED56.2 (DOUT), LED67.4 (DIN)
unnamed: LED57.4 (DIN), LED68.2 (DOUT)
unnamed: LED58.2 (DOUT), LED69.4 (DIN)
unnamed: LED59.4 (DIN), LED70.2 (DOUT)
unnamed: LED60.2 (DOUT), LED71.4 (DIN)
unnamed: LED62.4 (DIN), LED63.2 (DOUT)
unnamed: LED68.4 (DIN), LED69.2 (DOUT)
unnamed: LED70.4 (DIN), LED72.2 (DOUT)
unnamed: LED71.2 (DOUT), LED72.4 (DIN)
unnamed: R4.1, U1.4 (D+)
unnamed: R5.1, U1.3 (D-)
unnamed: R6.2, U1.33 (~HWB~/PE2)
unnamed: R7.1, ULED1.4 (DIN)
unnamed: U1.16 (XTAL2), Y1.3
unnamed: U1.17 (XTAL1), Y1.1
unnamed: ULED1.2 (DOUT), ULED2.4 (DIN)
unnamed: ULED2.2 (DOUT), ULED3.4 (DIN)
unnamed: ULED3.2 (DOUT), ULED4.4 (DIN)
unnamed: ULED4.2 (DOUT), ULED5.4 (DIN)
unnamed: ULED5.2 (DOUT), ULED6.4 (DIN)
unnamed: ULED6.2 (DOUT), ULED7.4 (DIN)
unnamed: ULED7.2 (DOUT), ULED8.4 (DIN)
unnamed: ULED8.2 (DOUT), ULED9.4 (DIN)
unnamed: ULED10.2 (DOUT), ULED11.4 (DIN)
unnamed: ULED9.2 (DOUT), ULED10.4 (DIN)
unnamed: ULED11.2 (DOUT), ULED12.4 (DIN)
unnamed: ULED12.2 (DOUT), ULED13.4 (DIN)
unnamed: ULED13.2 (DOUT), ULED14.4 (DIN)
VBUS: F1.2, J1.A4B9 (VBUS), J1.B4A9 (VBUS), U2.5 (VP)
col0: K_1.1 (COL), K_17.1 (COL), K_32.1 (COL), K_33.1 (COL), K_47.1 (COL), K_62.1 (COL), U1.41 (PF0)
col1: K_2.1 (COL), K_3.1 (COL), K_18.1 (COL), K_19.1 (COL), K_34.1 (COL), K_35.1 (COL), K_48.1 (COL), K_49.1 (COL), K_63.1 (COL), K_64.1 (COL), U1.40 (PF1)
col2: K_4.1 (COL), K_5.1 (COL), K_20.1 (COL), K_21.1 (COL), K_36.1 (COL), K_37.1 (COL), K_50.1 (COL), K_51.1 (COL), K_65.1 (COL), U1.39 (PF4)
col3: K_6.1 (COL), K_7.1 (COL), K_22.1 (COL), K_23.1 (COL), K_38.1 (COL), K_39.1 (COL), K_52.1 (COL), K_53.1 (COL), U1.38 (PF5)
col4: K_8.1 (COL), K_9.1 (COL), K_24.1 (COL), K_25.1 (COL), K_40.1 (COL), K_41.1 (COL), K_54.1 (COL), K_55.1 (COL), K_66.1 (COL), U1.19 (PD1)
col5: J2.4, K_10.1 (COL), K_11.1 (COL), K_26.1 (COL), K_27.1 (COL), K_42.1 (COL), K_43.1 (COL), K_56.1 (COL), K_57.1 (COL), K_67.1 (COL), K_68.1 (COL), U1.10 (PB2)
col6: K_12.1 (COL), K_13.1 (COL), K_28.1 (COL), K_29.1 (COL), K_44.1 (COL), K_58.1 (COL), K_59.1 (COL), K_69.1 (COL), K_70.1 (COL), U1.18 (PD0)
row0: D_2.1 (K), D_4.1 (K), D_6.1 (K), D_8.1 (K), D_10.1 (K), D_12.1 (K), D_15.1 (K), U1.8 (PB0)
row1: D_1.1 (K), D_3.1 (K), D_5.1 (K), D_7.1 (K), D_9.1 (K), D_11.1 (K), D_13.1 (K), D_16.1 (K), U1.12 (PB7)
row2: D_18.1 (K), D_20.1 (K), D_22.1 (K), D_24.1 (K), D_26.1 (K), D_28.1 (K), D_30.1 (K), U1.36 (PF7)
row3: D_17.1 (K), D_19.1 (K), D_21.1 (K), D_23.1 (K), D_25.1 (K), D_27.1 (K), D_29.1 (K), D_31.1 (K), J2.3, U1.9 (PB1)
row4: D_33.1 (K), D_35.1 (K), D_37.1 (K), D_39.1 (K), D_41.1 (K), D_43.1 (K), D_45.1 (K), U1.30 (PB6)
row5: D_34.1 (K), D_36.1 (K), D_38.1 (K), D_40.1 (K), D_42.1 (K), D_44.1 (K), D_46.1 (K), U1.31 (PC6)
row6: D_48.1 (K), D_50.1 (K), D_52.1 (K), D_54.1 (K), D_56.1 (K), D_58.1 (K), D_60.1 (K), U1.32 (PC7)
row7: D_47.1 (K), D_49.1 (K), D_51.1 (K), D_53.1 (K), D_55.1 (K), D_57.1 (K), D_59.1 (K), D_61.1 (K), U1.29 (PB5)
row8: D_63.1 (K), D_65.1 (K), D_67.1 (K), D_69.1 (K), D_71.1 (K), U1.37 (PF6)
row9: D_62.1 (K), D_64.1 (K), D_66.1 (K), D_68.1 (K), D_70.1 (K), D_72.1 (K), U1.20 (PD2)

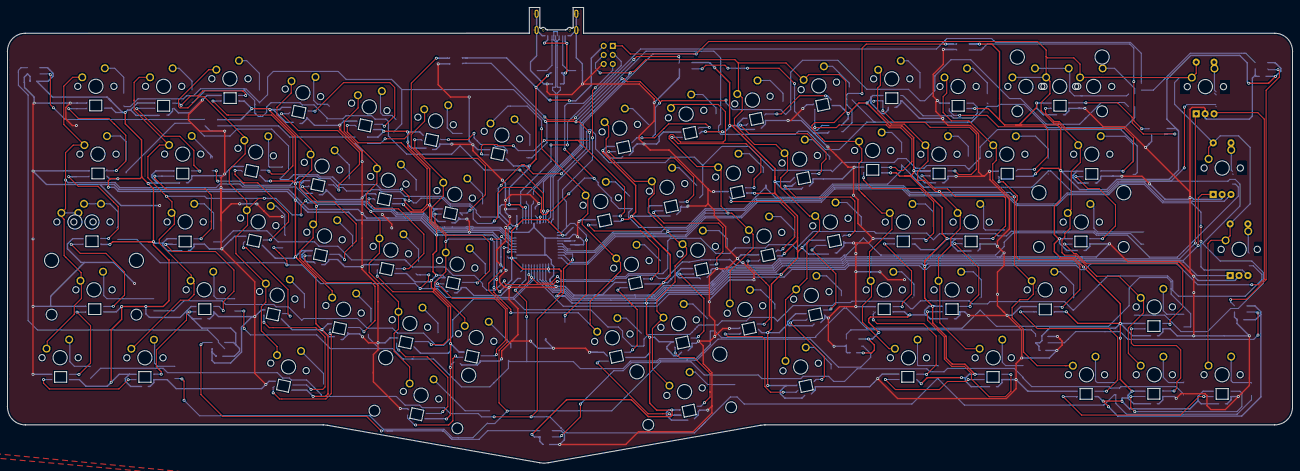
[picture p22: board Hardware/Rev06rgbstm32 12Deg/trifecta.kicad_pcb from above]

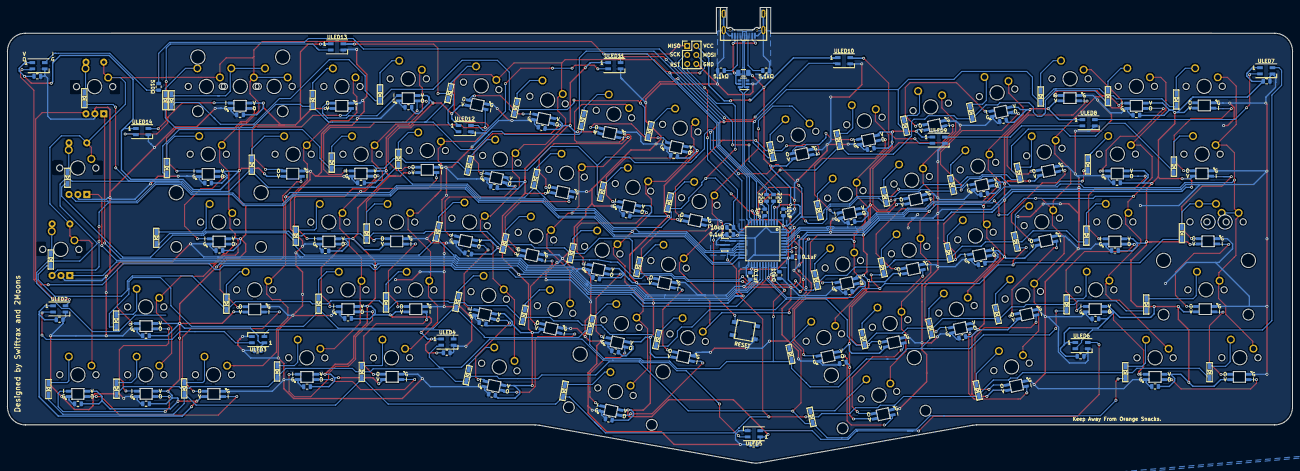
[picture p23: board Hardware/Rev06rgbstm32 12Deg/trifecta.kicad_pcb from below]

Board: 2 copper layers, 361.0 x 128.0 mm, 285 parts (210 on the bottom side), 189 nets.

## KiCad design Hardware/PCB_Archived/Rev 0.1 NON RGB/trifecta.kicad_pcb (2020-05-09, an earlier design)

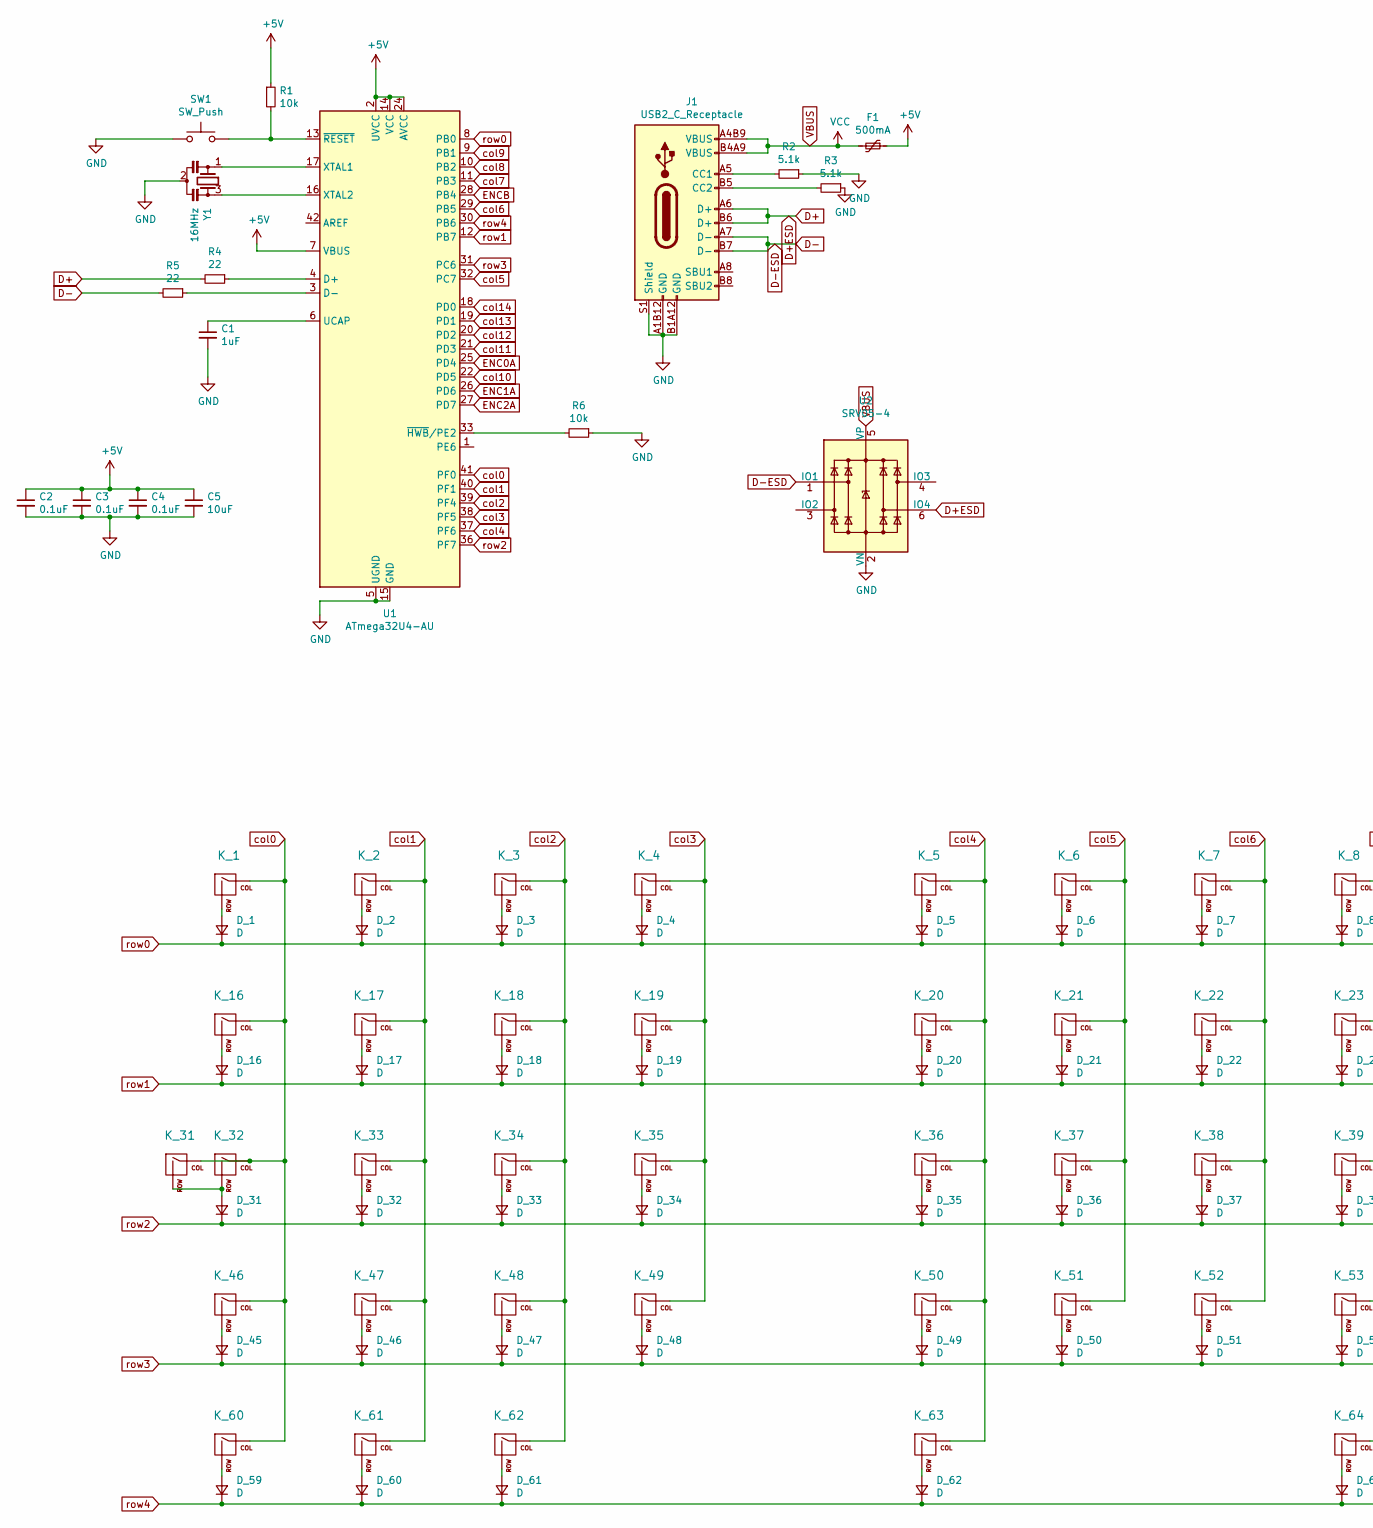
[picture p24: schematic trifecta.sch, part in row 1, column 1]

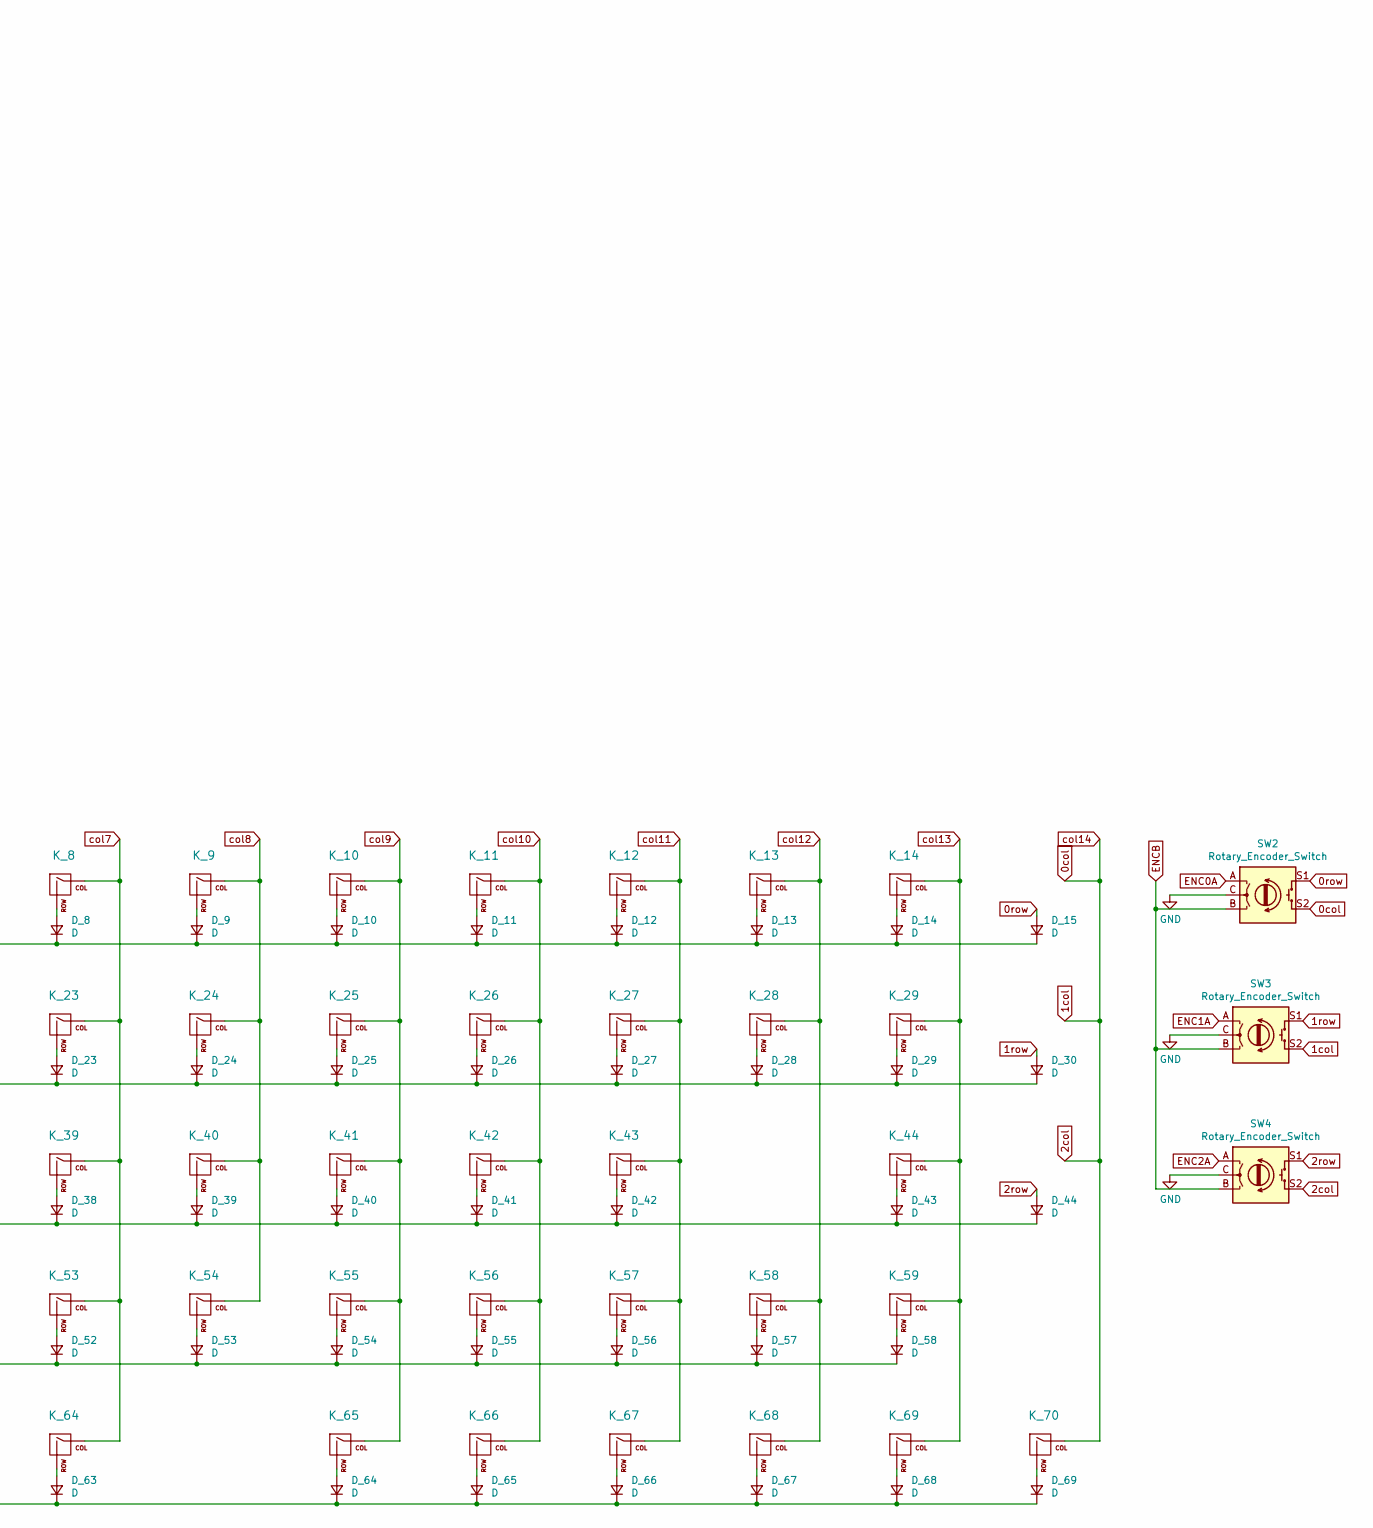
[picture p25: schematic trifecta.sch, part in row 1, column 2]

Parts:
C1: 1uF; C_0805_2012Metric
C2, C3, C4: 0.1uF; C_0805_2012Metric
C5: 10uF; C_0805_2012Metric
D_1, D_2, D_3, D_4, D_5, D_6, D_7, D_8, D_9, D_10, D_11, D_12, D_13, D_14, D_15, D_16, D_17, D_18, D_19, D_20, D_21, D_22, D_23, D_24, D_25, D_26, D_27, D_28, D_29, D_30, D_31, D_32, D_33, D_34, D_35, D_36, D_37, D_38, D_39, D_40, D_41, D_42, D_43, D_44, D_45, D_46, D_47, D_48, D_49, D_50, D_51, D_52, D_53, D_54, D_55, D_56, D_57, D_58, D_59, D_60, D_61, D_62, D_63, D_64, D_65, D_66, D_67, D_68, D_69: D; D_SOD-123
F1: 500mA; Fuse_1206_3216Metric
J1: USB2_C_Receptacle; Mid_Mount-USB_C_HandSoldering
K_1, K_2, K_3, K_4, K_5, K_6, K_7, K_8, K_9, K_10, K_11, K_12, K_13, K_17, K_18, K_19, K_20, K_21, K_22, K_23, K_24, K_25, K_26, K_27, K_28, K_33, K_34, K_35, K_36, K_37, K_38, K_39, K_40, K_41, K_42, K_43, K_47, K_48, K_49, K_50, K_51, K_52, K_53, K_54, K_55, K_56, K_57, K_59, K_68, K_69, K_70: KEYSW; MXOnly-1U-NoLED
K_14: KEYSW; MXOnly-2U-ReversedStabilizers-NoLED
K_16, K_29: KEYSW; MXOnly-1.5U-NoLED
K_31, K_60, K_61, K_62, K_65, K_66, K_67: KEYSW; MXOnly-1.25U-NoLED
K_32, K_58: KEYSW; MXOnly-1.75U-NoLED
K_44, K_46, K_64: KEYSW; MXOnly-2.25U-ReversedStabilizers-NoLED
K_63: KEYSW; MXOnly-2.75U-ReversedStabilizers-NoLED
R1, R6: 10k; R_0805_2012Metric
R2, R3: 5.1k; R_0805_2012Metric
R4, R5: 22; R_0805_2012Metric
SW1: SW_Push; SKQG-1155865
SW2, SW3, SW4: Rotary_Encoder_Switch; RotaryEncoder_EC11
U1: ATmega32U4-AU; TQFP-44_10x10mm_P0.8mm
U2: SRV05-4; SOT-23-6
Y1: 16MHz; Resonator_SMD_muRata_CSTxExxV-3Pin_3.0x1.1mm_HandSoldering_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

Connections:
0col: K_70.1 (COL), SW2.S2, SW3.S2, SW4.S2, U1.18 (PD0)
0row: D_15.2 (A), SW2.S1
1row: D_30.2 (A), SW3.S1
2row: D_44.2 (A), SW4.S1
+5V: C2.1, C3.1, C4.1, C5.1, F1.1, R1.1, U1.2 (UVCC), U1.7 (VBUS), U1.14 (VCC), U1.24 (AVCC), U1.34 (VCC), U1.44 (AVCC)
D+: J1.A6 (D+), J1.B6 (D+), R4.2, U2.6 (IO4)
D-: J1.A7 (D-), J1.B7 (D-), R5.2, U2.1 (IO1)
ENC0A: SW2.A, U1.25 (PD4)
ENC1A: SW3.A, U1.26 (PD6)
ENC2A: SW4.A, U1.27 (PD7)
ENCB: SW2.B, SW3.B, SW4.B, U1.28 (PB4)
GND: C1.2, C2.2, C3.2, C4.2, C5.2, J1.A1B12 (GND), J1.B1A12 (GND), J1.S1 (Shield), R2.1, R3.1, R6.1, SW1.1, SW2.C, SW3.C, SW4.C, U1.5 (UGND), U1.15 (GND), U1.23 (GND), U1.35 (GND), U1.43 (GND), U2.2 (VN), Y1.2
unnamed: C1.1, U1.6 (UCAP)
unnamed: D_1.2 (A), K_1.2 (ROW)
unnamed: D_2.2 (A), K_2.2 (ROW)
unnamed: D_3.2 (A), K_3.2 (ROW)
unnamed: D_4.2 (A), K_4.2 (ROW)
unnamed: D_5.2 (A), K_5.2 (ROW)
unnamed: D_6.2 (A), K_6.2 (ROW)
unnamed: D_7.2 (A), K_7.2 (ROW)
unnamed: D_8.2 (A), K_8.2 (ROW)
unnamed: D_9.2 (A), K_9.2 (ROW)
unnamed: D_10.2 (A), K_10.2 (ROW)
unnamed: D_11.2 (A), K_11.2 (ROW)
unnamed: D_12.2 (A), K_12.2 (ROW)
unnamed: D_13.2 (A), K_13.2 (ROW)
unnamed: D_14.2 (A), K_14.2 (ROW)
unnamed: D_16.2 (A), K_16.2 (ROW)
unnamed: D_17.2 (A), K_17.2 (ROW)
unnamed: D_18.2 (A), K_18.2 (ROW)
unnamed: D_19.2 (A), K_19.2 (ROW)
unnamed: D_20.2 (A), K_20.2 (ROW)
unnamed: D_21.2 (A), K_21.2 (ROW)
unnamed: D_22.2 (A), K_22.2 (ROW)
unnamed: D_23.2 (A), K_23.2 (ROW)
unnamed: D_24.2 (A), K_24.2 (ROW)
unnamed: D_25.2 (A), K_25.2 (ROW)
unnamed: D_26.2 (A), K_26.2 (ROW)
unnamed: D_27.2 (A), K_27.2 (ROW)
unnamed: D_28.2 (A), K_28.2 (ROW)
unnamed: D_29.2 (A), K_29.2 (ROW)
unnamed: D_31.2 (A), K_31.2 (ROW), K_32.2 (ROW)
unnamed: D_32.2 (A), K_33.2 (ROW)
unnamed: D_33.2 (A), K_34.2 (ROW)
unnamed: D_34.2 (A), K_35.2 (ROW)
unnamed: D_35.2 (A), K_36.2 (ROW)
unnamed: D_36.2 (A), K_37.2 (ROW)
unnamed: D_37.2 (A), K_38.2 (ROW)
unnamed: D_38.2 (A), K_39.2 (ROW)
unnamed: D_39.2 (A), K_40.2 (ROW)
unnamed: D_40.2 (A), K_41.2 (ROW)
unnamed: D_41.2 (A), K_42.2 (ROW)
unnamed: D_42.2 (A), K_43.2 (ROW)
unnamed: D_43.2 (A), K_44.2 (ROW)
unnamed: D_45.2 (A), K_46.2 (ROW)
unnamed: D_46.2 (A), K_47.2 (ROW)
unnamed: D_47.2 (A), K_48.2 (ROW)
unnamed: D_48.2 (A), K_49.2 (ROW)
unnamed: D_49.2 (A), K_50.2 (ROW)
unnamed: D_50.2 (A), K_51.2 (ROW)
unnamed: D_51.2 (A), K_52.2 (ROW)
unnamed: D_52.2 (A), K_53.2 (ROW)
unnamed: D_53.2 (A), K_54.2 (ROW)
unnamed: D_54.2 (A), K_55.2 (ROW)
unnamed: D_55.2 (A), K_56.2 (ROW)
unnamed: D_56.2 (A), K_57.2 (ROW)
unnamed: D_57.2 (A), K_58.2 (ROW)
unnamed: D_58.2 (A), K_59.2 (ROW)
unnamed: D_59.2 (A), K_60.2 (ROW)
unnamed: D_60.2 (A), K_61.2 (ROW)
unnamed: D_61.2 (A), K_62.2 (ROW)
unnamed: D_62.2 (A), K_63.2 (ROW)
unnamed: D_63.2 (A), K_64.2 (ROW)
unnamed: D_64.2 (A), K_65.2 (ROW)
unnamed: D_65.2 (A), K_66.2 (ROW)
unnamed: D_66.2 (A), K_67.2 (ROW)
unnamed: D_67.2 (A), K_68.2 (ROW)
unnamed: D_68.2 (A), K_69.2 (ROW)
unnamed: D_69.2 (A), K_70.2 (ROW)
unnamed: J1.A5 (CC1), R2.2
unnamed: J1.B5 (CC2), R3.2
unnamed: R1.2, SW1.2, U1.13 (~RESET)
unnamed: R4.1, U1.4 (D+)
unnamed: R5.1, U1.3 (D-)
unnamed: R6.2, U1.33 (~HWB~/PE2)
unnamed: U1.16 (XTAL2), Y1.3
unnamed: U1.17 (XTAL1), Y1.1
VBUS: F1.2, J1.A4B9 (VBUS), J1.B4A9 (VBUS), U2.5 (VP)
col0: K_1.1 (COL), K_16.1 (COL), K_31.1 (COL), K_32.1 (COL), K_46.1 (COL), K_60.1 (COL), U1.41 (PF0)
col1: K_2.1 (COL), K_17.1 (COL), K_33.1 (COL), K_47.1 (COL), K_61.1 (COL), U1.40 (PF1)
col2: K_3.1 (COL), K_18.1 (COL), K_34.1 (COL), K_48.1 (COL), K_62.1 (COL), U1.39 (PF4)
col3: K_4.1 (COL), K_19.1 (COL), K_35.1 (COL), K_49.1 (COL), U1.38 (PF5)
col4: K_5.1 (COL), K_20.1 (COL), K_36.1 (COL), K_50.1 (COL), K_63.1 (COL), U1.37 (PF6)
col5: K_6.1 (COL), K_21.1 (COL), K_37.1 (COL), K_51.1 (COL), U1.32 (PC7)
col6: K_7.1 (COL), K_22.1 (COL), K_38.1 (COL), K_52.1 (COL), U1.29 (PB5)
col7: K_8.1 (COL), K_23.1 (COL), K_39.1 (COL), K_53.1 (COL), K_64.1 (COL), U1.11 (PB3)
col8: K_9.1 (COL), K_24.1 (COL), K_40.1 (COL), K_54.1 (COL), U1.10 (PB2)
col9: K_10.1 (COL), K_25.1 (COL), K_41.1 (COL), K_55.1 (COL), K_65.1 (COL), U1.9 (PB1)
col10: K_11.1 (COL), K_26.1 (COL), K_42.1 (COL), K_56.1 (COL), K_66.1 (COL), U1.22 (PD5)
col11: K_12.1 (COL), K_27.1 (COL), K_43.1 (COL), K_57.1 (COL), K_67.1 (COL), U1.21 (PD3)
col12: K_13.1 (COL), K_28.1 (COL), K_58.1 (COL), K_68.1 (COL), U1.20 (PD2)
col13: K_14.1 (COL), K_29.1 (COL), K_44.1 (COL), K_59.1 (COL), K_69.1 (COL), U1.19 (PD1)
row0: D_1.1 (K), D_2.1 (K), D_3.1 (K), D_4.1 (K), D_5.1 (K), D_6.1 (K), D_7.1 (K), D_8.1 (K), D_9.1 (K), D_10.1 (K), D_11.1 (K), D_12.1 (K), D_13.1 (K), D_14.1 (K), D_15.1 (K), U1.8 (PB0)
row1: D_16.1 (K), D_17.1 (K), D_18.1 (K), D_19.1 (K), D_20.1 (K), D_21.1 (K), D_22.1 (K), D_23.1 (K), D_24.1 (K), D_25.1 (K), D_26.1 (K), D_27.1 (K), D_28.1 (K), D_29.1 (K), D_30.1 (K), U1.12 (PB7)
row2: D_31.1 (K), D_32.1 (K), D_33.1 (K), D_34.1 (K), D_35.1 (K), D_36.1 (K), D_37.1 (K), D_38.1 (K), D_39.1 (K), D_40.1 (K), D_41.1 (K), D_42.1 (K), D_43.1 (K), D_44.1 (K), U1.36 (PF7)
row3: D_45.1 (K), D_46.1 (K), D_47.1 (K), D_48.1 (K), D_49.1 (K), D_50.1 (K), D_51.1 (K), D_52.1 (K), D_53.1 (K), D_54.1 (K), D_55.1 (K), D_56.1 (K), D_57.1 (K), D_58.1 (K), U1.31 (PC6)
row4: D_59.1 (K), D_60.1 (K), D_61.1 (K), D_62.1 (K), D_63.1 (K), D_64.1 (K), D_65.1 (K), D_66.1 (K), D_67.1 (K), D_68.1 (K), D_69.1 (K), U1.30 (PB6)

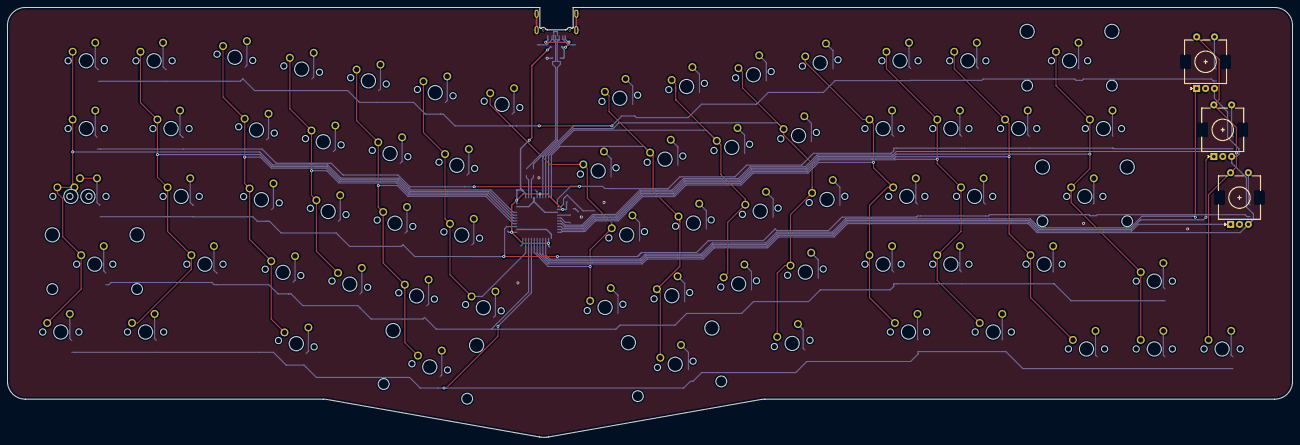
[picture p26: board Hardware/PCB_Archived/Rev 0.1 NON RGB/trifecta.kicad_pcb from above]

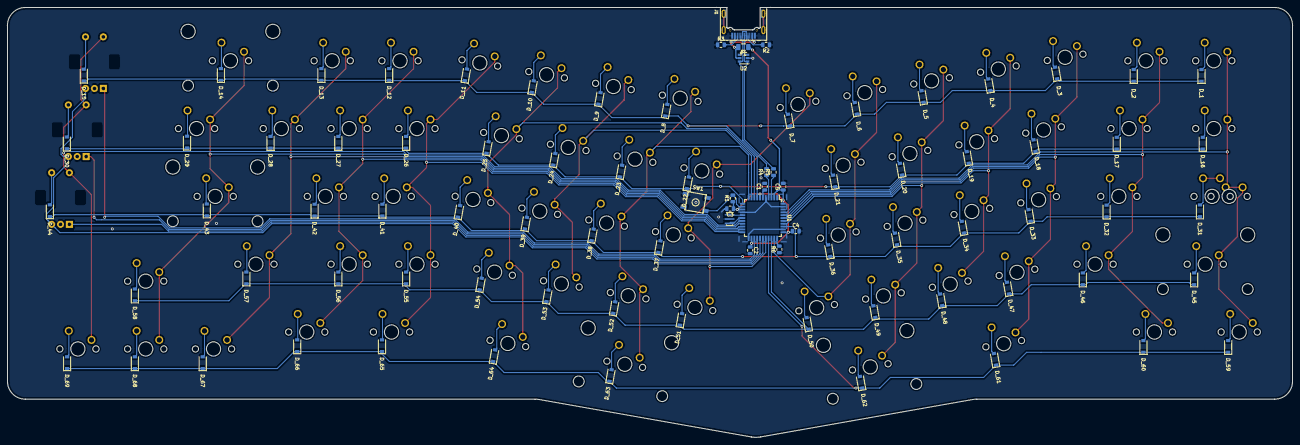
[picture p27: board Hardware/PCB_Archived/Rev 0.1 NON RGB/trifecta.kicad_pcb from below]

Board: 2 copper layers, 361.0 x 120.8 mm, 156 parts (86 on the bottom side), 107 nets.

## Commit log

2020-04-14 Remove Tracks
    [JST-SR-4.step, Molex-0548190519.step, PJ-3200B.step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]
2020-04-14 Add Encoders
    [keyboard.kicad_pcb, keyboard.sch]
2020-04-14 Added PCB Edge Cuts
    [edge_cuts.dxf, keyboard.kicad_pcb, plate_temp.dxf]
2020-04-14 Redo Edge Cuts
    [edge_cuts.dxf, keyboard.kicad_pcb]
2020-04-14 Wire USB
    [keyboard.kicad_pcb]
2020-04-14 Wire Matrix + Place MCU
    [keyboard.kicad_pcb]
2020-04-15 Assign Rows + Cols to pins
    [keyboard.kicad_pcb, keyboard.sch]
2020-04-15 Place Traces for matrix + gnd fill
    [keyboard.kicad_pcb, unnamed.kicad_pcb, unnamed.sch]
2020-04-16 Move Switches, remove tracks, add new layout drawing
2020-04-16 Wire switch Matrix together
    [unnamed.kicad_pcb]
2020-04-16 Wire MCU + GND fill
    [edge_cuts.dxf, plate_temp.dxf, unnamed.kicad_pcb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]
2020-04-17 Add Fusion Files
    [Unnamed.f3d, bottom dxf.dxf]
2020-04-17 Add new case
    [Trifecta.f3d, pcb.dxf, plate.dxf]
2020-04-18 Add new case design
    5mm top bezel
    Should be CNC ready
    [Trifecta.f3d, pcb.dxf, plate.dxf]
2020-04-19 Add Stacked Acrylic case files
    [Bottom.dxf, BottomElevate.dxf, MidLayer.dxf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]
2020-04-20 Add Top layer for encoder shaft
    [TopEncoders.dxf]
2020-04-21 Add more renders + Case step file
    [TrifectaCase.step]
2020-05-06 Add New Case and Drawing
    [Bottom.step, Plate.step, Top.step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]
2020-05-07 Reorganize Files and add step files
    [Bottom.step, Plate.step, Top.step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]
2020-05-07 Add new case revision
    [bottom.step, plate.step, top.step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]
2020-05-07 Enlarge encoder cutouts to allow it to be put in and out
    [plate.step]
2020-05-07 Change side edges of botom half
    [bottom.step]
2020-05-07 Remove 5th rubber foot inlay + more renders
    [bottom.step]
2020-05-07 Add RGB board + Move old design over
    [JST-SR-4.step, Molex-0548190519.step, PJ-3200B.step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]
2020-05-08 Add homing bars to case + more renders
    [bottom.step, top.step]
2020-05-09 Names of PCBs
    [trifecta.csv, trifecta.kicad_pcb, trifecta.sch]
2020-05-09 Edit Case to have uniform bottom
    [bottom.step, plate.step, top.step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]
2020-05-09 Edit top piece holes
    [top.step]
2020-05-10 Add bottom logo
    [bottom.step, plate.step, top.step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]
2020-05-10 Edit Clearances and logo emboss
    [Final Case.step, bottom.step, top.step]
2020-05-11 Make Logo bigger
    [bottom.step]
2020-05-11 Add Case .obj and .step
    [Final Case.step, Trifecta Assembled.step, Trifecta Case.obj]
2020-05-12 Update Laser files for Rev 0.0 pcb
    [Bottom.dxf, BottomElevate.dxf, Foot1.dxf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]
2020-05-12 Add Step of PCB
    [trifecta.kicad_pcb]
2020-05-21 PCB Final
    [2U.dxf, 2U_switch_plate_cutout.dxf, 3313J-1-202E.stp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]
2020-07-05 Add new laser cut DXF files
    [BackPlate.dxf, BigFoot.dxf, Bottom.dxf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]
2020-07-05 Update Gerbers
    [trifecta-B_Cu.gbl, trifecta-B_Mask.gbs, trifecta-B_SilkS.gbo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]
2020-07-30 New Board
    [JST-SR-4.step, Molex-0548190519.step, PJ-3200B.step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]
2020-08-05 Clean up silkscreens, Add ground fill, Generate new gerbers
    [trifecta-B_Cu.gbl, trifecta-B_Mask.gbs, trifecta-B_SilkS.gbo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]
2020-08-05 Edit resistor silkscreen, Generate Gerbers
    [trifecta-B_Cu.gbl, trifecta-B_Mask.gbs, trifecta-B_SilkS.gbo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]
2020-08-06 LED Update
    [trifecta.kicad_pcb]
2020-08-06 Flip backspace stab regenerate gerbers
    [trifecta-B_Cu.gbl, trifecta-B_Mask.gbs, trifecta-B_SilkS.gbo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]
2020-08-07 08/07 -2
    [JST-SR-4.step, Molex-0548190519.step, PJ-3200B.step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]
2020-08-07 8/7 Final
    [trifecta.kicad_pcb, trifecta.sch]
2020-08-07 Clean up silkscreen, tracks, and generate gerbers
    [trifecta-B_Cu.gbl, trifecta-B_Mask.gbs, trifecta-B_SilkS.gbo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]
2020-08-07 Fix more traces, regenerate gerbers
    [trifecta-B_Cu.gbl, trifecta-B_Mask.gbs, trifecta-B_SilkS.gbo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]
2020-08-07 Edit Silkscreens for HS version
    TODO: clean up tracks and add silkscreen art
    [trifecta.kicad_pcb, trifecta.sch]
2020-08-08 Add copper fill 0.5
    [trifecta-B_Cu.gbl, trifecta-B_Mask.gbs, trifecta-B_SilkS.gbo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]
2020-08-08 Revert "Edit Silkscreens for HS version"
    This reverts commit 5a8b713c0dac6e6c9a90fc558c8fc8e6b1fe5ec3.
    [trifecta.kicad_pcb, trifecta.sch]
2020-08-08 Clean up silkscreens, regenerate gerbers
    [trifecta-B_Cu.gbl, trifecta-B_Mask.gbs, trifecta-B_SilkS.gbo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]
2020-08-16 Fix silkscreen + generate gerbers
    [trifecta-B_Cu.gbl, trifecta-B_Mask.gbs, trifecta-B_SilkS.gbo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]
2020-08-17 move usb port out
    [trifecta.kicad_pcb]
2020-08-21 8/21 -2
    [trifecta.kicad_pcb]
2020-08-21 8/21 -4
    [JST-SR-4.step, Molex-0548190519.step, PJ-3200B.step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]
2020-09-06 RGB Matrix
    [trifecta.sch]
2020-10-16 Trifecta Board
    [trifecta.kicad_pcb]
2020-10-16 Trifecta Keyboard
    [trifecta.kicad_pcb]
2020-10-18 Add case redesign
2021-01-24 Rev0.6 Hotswap
    [JST-SR-4.step, Molex-0548190519.step, PJ-3200B.step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]
2021-01-24 Degree Notation for PCBs
    [JST-SR-4.step, Molex-0548190519.step, PJ-3200B.step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]
2021-01-24 Remove Edge Cuts
    [edge_cuts.dxf]
2021-01-24 Added folder for STM32 PCB
    [JST-SR-4.step, Molex-0548190519.step, PJ-3200B.step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]
